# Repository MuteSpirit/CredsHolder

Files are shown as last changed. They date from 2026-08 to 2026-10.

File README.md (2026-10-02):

<!--
Copyright (C)  2026  Ivan Efimov aka MuteSpirit <mutespirit@yandex.ru>.

Permission is granted to copy, distribute and/or modify this document
under the terms of the GNU Free Documentation License, Version 1.3
or any later version published by the Free Software Foundation;
with no Invariant Sections, no Front-Cover Texts, and no Back-Cover Texts.
A copy of the license is included in the section entitled "GNU
Free Documentation License".
-->

# CredsHolder

Hardware credentials manager.

Secure replacement of stickers on monitor (and other similar stuff) with login and passwords.

CredsHolder makes it easier to use good complex and unique passwords for your accounts on different web sites and other applications. 

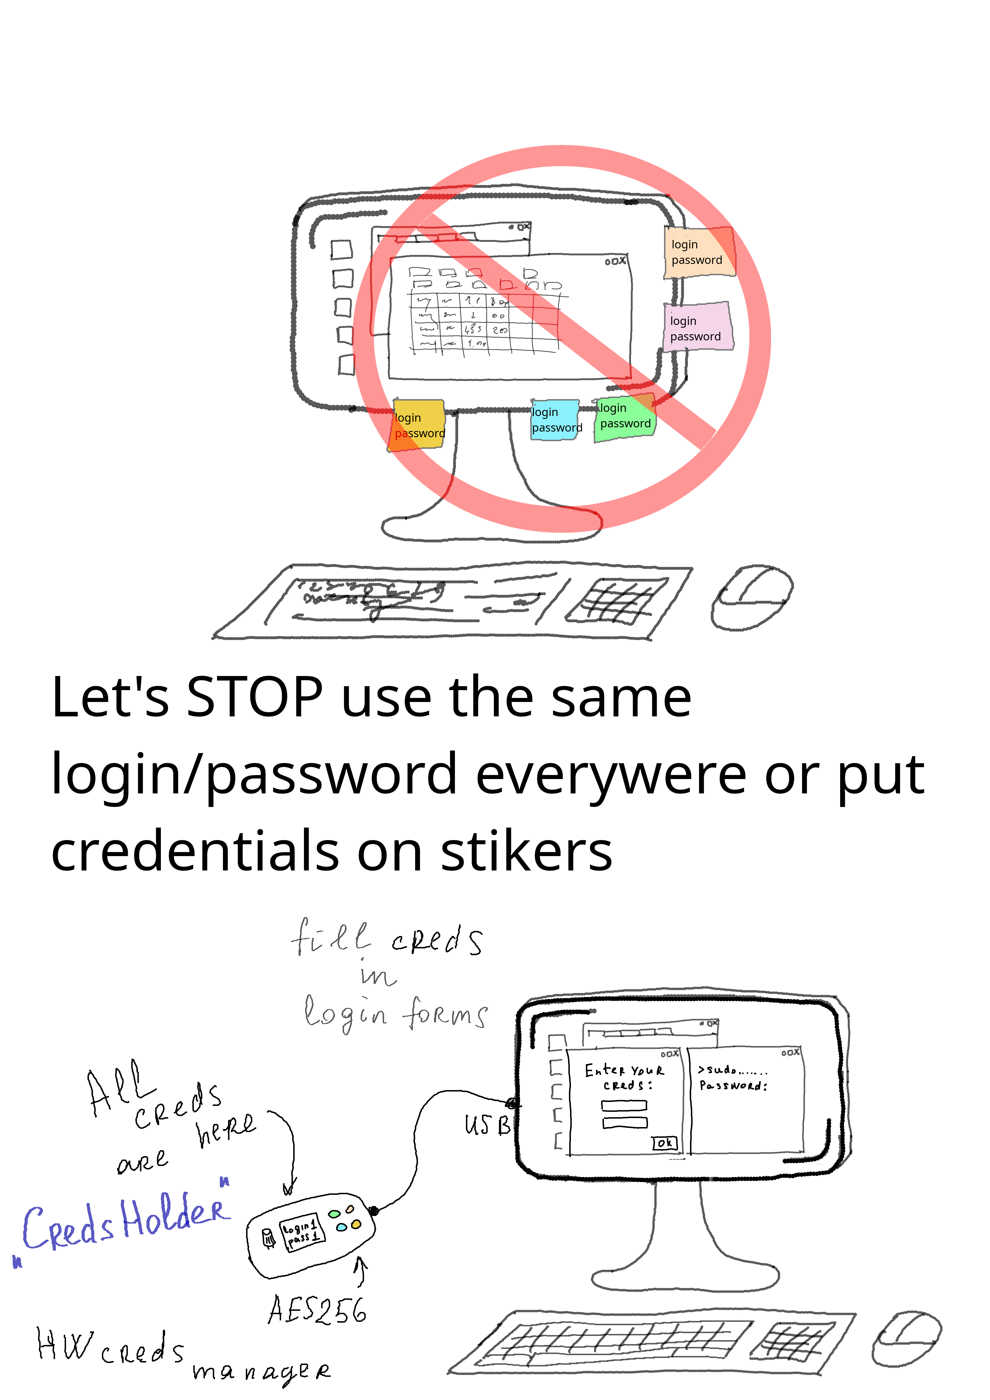
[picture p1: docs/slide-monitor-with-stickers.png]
Slide 1


## Code License

```
Hardware Credential Manager "CredsHolder"
Copyright (C) 2026 Ivan Efimov aka MuteSpirit <mutespirit@yandex.ru>

This program is free software: you can redistribute it and/or modify it under the terms of the GNU General Public License as published by the Free Software Foundation, either version 3 of the License, or (at your option) any later version.

This program is distributed in the hope that it will be useful, but WITHOUT ANY WARRANTY; without even the implied warranty of MERCHANTABILITY or FITNESS FOR A PARTICULAR PURPOSE. See the GNU General Public License for more details.

You should have received a copy of the GNU General Public License along with this program. If not, see <https://www.gnu.org/licenses/>.
```

## Documentation License

Copyright (C)  2026  Ivan Efimov aka MuteSpirit <mutespirit@yandex.ru>.

Permission is granted to copy, distribute and/or modify this document
under the terms of the GNU Free Documentation License, Version 1.3
or any later version published by the Free Software Foundation;
with no Invariant Sections, no Front-Cover Texts, and no Back-Cover Texts.
A copy of the license is included in the section entitled [GNU
Free Documentation License](COPYING.FDL-1.3.md).

# See Also

* [CredsHolder Project Requirements Doc](proposals/creds-holder.md)

# Project News

Current stage - MVP.

## 02 Oct 2026

* Demo variant:
  * no authentication
  * no storage on flash
  * 3 hard-coded accounts
  * accounts menu
  * account fields menu
  * typing login and password
  * navigation with device tilts (forward, backward, clockwise and counterclockwise)
  * vibration motor to feedback User about correct tilt angle

## 27 Aug 2026

* Project code license has been changed to GPLv3-or-later. See reasons in [relevant proposals](proposals/creds-holder-license.md).
* Project documentation license is [GNU Free Documentation License](COPYING.FDL-1.3.md) now.

## 21 Aug 2026

* Fritzing part for NRF52840 Pro Micro board finished. See [relevant README](./fritzing/README.md)
* Starting POC No 3 "VeraCrypt volume on microSD card (NRF52840 Pro Micro)"

## 19 Aug 2026

* Two POCs finished successfully:
  * POC No1 "UI with position sensor (Arduino Uno)" - see [README](poc/ui-mpu-6050-with-oled-on-arduino-uno/README.md)
  * POC No2 "UI with position sensor (NRF52840 Pro Micro)" - see [README](poc/ui-mpu-6050-with-oled-on-nrf52840/README.md)

## 17 Aug 2026

* [CredsHolder UI High Level Design](proposals/creds-holder-ui.md) with 3 possible variants of device UI

## 15 Aug 2026

* Finished [CredsHolder Storage High Level Design](proposals/creds-holder-storage.md)
  * Encrypted VeraCrypt volume on removable microSD card
  * PIN for CredsHolder unlock but custom complex password and non-default PIM for VeraCrypt volume encryption
  * FAT inside encrypted volume
  * Any suitable file format for application data, i.e. SQLite
  * See all details in design

## 13 Aug 2026

* Finished [CredsHolder Authentication High Level Design](proposals/creds-holder-auth.md)
  * PIN for CredsHolder authentication
  * No one button or encoder in Device
  * Enter PIN via Morse code
  * See all details in design

## 12 Aug 2026

* Finished [CredsHolder Project Requirements Doc](proposals/creds-holder.md)
* Low Level Design for Authentication is started

## 07 Aug 2026

* Close PasswordWand (clone of PasswordPump with modified code) project as deprecated
* Project has been renamed and started from scratch
  * Reason 1: license has been changed to MIT. I hope that will help for distribution.
  * Reason 2: device SW and HW redesign is needed. Original PasswordPump code base is very complex to be maintainable and extendable.
  * Reason 3: to be not a fork repo of PasswordPump will allow to configure Git LFS and store docs pictures originals in Git.
  * Reason 4: do at least OpenSource project design and development accordign all best practices and without rush.

## This project was originally fork of ...

... https://github.com/seawarrior181/PasswordPump

I'd like to thank Dan Murphy for PasswordPump. It's cool idea and device.
I'm appreciate how many features has been implemented in orignal sketch.

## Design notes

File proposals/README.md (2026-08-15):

# Proposals

| Doc | Comment | 
| --- | --- |
| [CredsHolder Project Requirements Doc](creds-holder.md) |  |
| [CredsHolder Authentication High Level Design](creds-holder-auth.md) | <br/>PIN will unlock device<br/>OLED will be hidden inside case or User will receive PIN suggestion using Morse code via vibration<br/>Concrete UI is not chosen |
| [CredsHolder Storage High Level Design](creds-holder-storage.md) | <br/>Encrypted VeraCrypt volume on removable microSD card together with VeraCrypt portable applications<br/>PIN for CredsHolder unlock but custom complex password and non-default PIM for VeraCrypt volume encryption<br/>VeraCrypt volume will have FAT FS and contain SQLite DBs with application data |
| [CredsHolder UI High Level Design](creds-holder-ui.md) | Doc is started |

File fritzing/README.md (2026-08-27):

<!--
Copyright (C)  2026  Ivan Efimov aka MuteSpirit <mutespirit@yandex.ru>.

Permission is granted to copy, distribute and/or modify this document
under the terms of the GNU Free Documentation License, Version 1.3
or any later version published by the Free Software Foundation;
with no Invariant Sections, no Front-Cover Texts, and no Back-Cover Texts.
A copy of the license is included in the section entitled "GNU
Free Documentation License".
-->

# Fritzing

## Self-done Parts

### Tenstar Robot NRF52840 Pro Micro

That microcontroller board Fritzing part was not founded in Internet and I had to do that myself.

Import next one into your Fritzing to be able use NRF52840 Pro Micro board in schemas: [NRF52840 Pro Micro](./parts/nrf52840_pro_micro/NRF52840 Pro Micro.fzpz)

Some notes:
* All needed parts Breadboard, Schematic, PCB, Connectors and Metadata has been added following [Fritzings Graphic Standards](https://fritzing.org/fritzings-graphic-standards) but ...
* .. I've tried to make board contacts as similar as possible to real board but I had no PDF/PostScript/SVG breadboard schema from manufacturer and there is absolutely no guarantee that exporting PCB will give expected results.
* So that fritzing part is good enough for making schemas in Fritzing and that's enough for nearest goals

#### Links

* https://www.beachyuk.com/blog/connecting-and-testing-promicro-nrf52840-clones
* https://github.com/ICantMakeThings/Nicenano-NRF52-Supermini-PlatformIO-Support#1
* https://doxygen.riot-os.org/group__boards__pro-micro-nrf52840.html
* https://tenstar.pro/nrf52840-pinout/
* https://chat.nologo.tech/d/80
* https://tinygo.org/docs/reference/microcontrollers/boards/nicenano/
* https://nrfconnectdocs.nordicsemi.com/ncs/3.2.4/zephyr/boards/others/promicro_nrf52840/doc/index.html

## Downloaded Parts

| | URL |
| :---: | :---: |
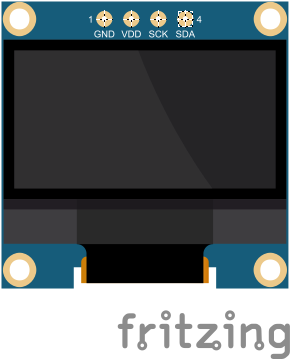
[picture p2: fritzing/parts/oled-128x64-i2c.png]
OLED 128x64 I2C
|  | [Link](https://github.com/AlexGyver/GyverKIT/blob/master/Fritzing%20parts/OLED%20128x64%20I2C.fzpz) |
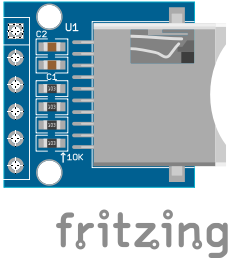
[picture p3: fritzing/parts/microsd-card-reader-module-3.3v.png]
MicroSD Card Reader 3.3V
|  | [Link](https://digitalconcepts.net.au/fritzing/content/support/parts/microSD%20Card%20Reader.fzpz) |
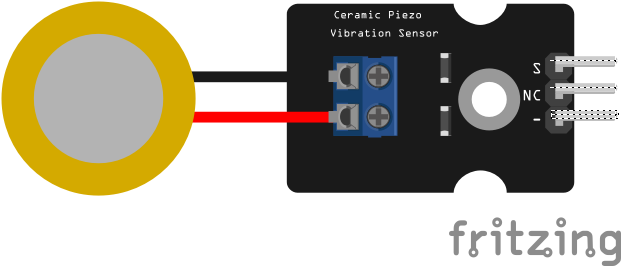
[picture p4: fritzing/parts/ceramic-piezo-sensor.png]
Ceramic Piezoelectric Sensor
|  | [Link](https://forum.fritzing.org/t/piezoelectric-ceramic-vibration-sensors/33600) |
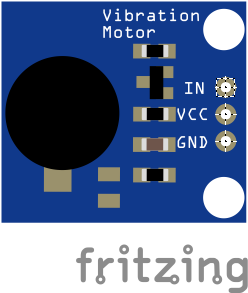
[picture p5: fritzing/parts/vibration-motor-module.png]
Vibration Motor Module 5V
|  | [Link](https://forum.fritzing.org/t/looking-for-a-vibration-module/26877) |

#### Links

* https://digitalconcepts.net.au/fritzing/index.php?op=parts

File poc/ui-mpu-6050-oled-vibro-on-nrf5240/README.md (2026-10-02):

# POC No 4 UI (OLED, MPU6050, vibration motor)

## Goal

Help user to sense needed tilt angle.

## Proposals

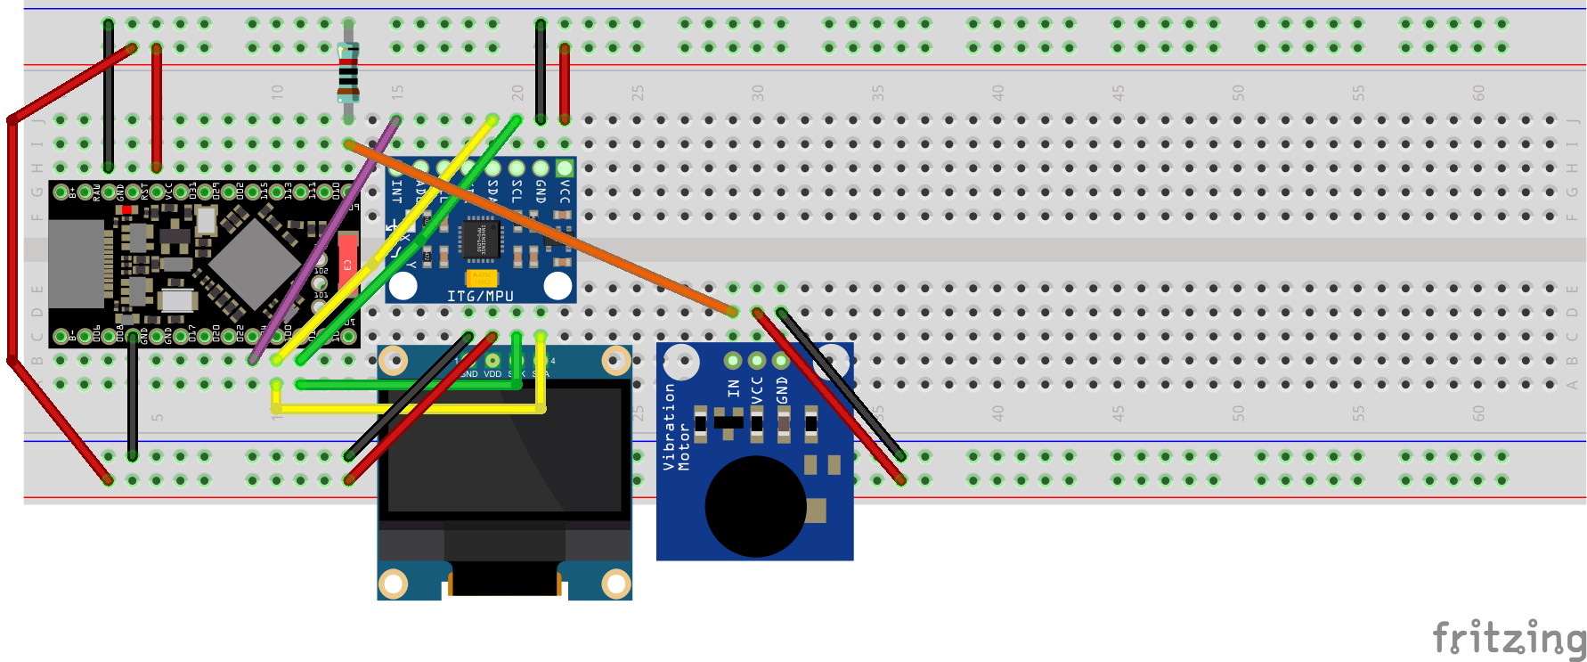
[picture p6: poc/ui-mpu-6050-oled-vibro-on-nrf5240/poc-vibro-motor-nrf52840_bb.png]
Breadboard Schema


Make very short vibration on tilting device up to threshold angle but before return device back to horizontal position.

## Results

Touching senses are cool. I'm feeling more navigation control.

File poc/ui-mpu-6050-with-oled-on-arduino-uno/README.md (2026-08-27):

<!--
Copyright (C)  2026  Ivan Efimov aka MuteSpirit <mutespirit@yandex.ru>.

Permission is granted to copy, distribute and/or modify this document
under the terms of the GNU Free Documentation License, Version 1.3
or any later version published by the Free Software Foundation;
with no Invariant Sections, no Front-Cover Texts, and no Back-Cover Texts.
A copy of the license is included in the section entitled "GNU
Free Documentation License".
-->

## Summary

POC proved that it's possible to detect device tilts (on left, on right, forward, backward) using MPU6050 and Arduino Uno as a controller:

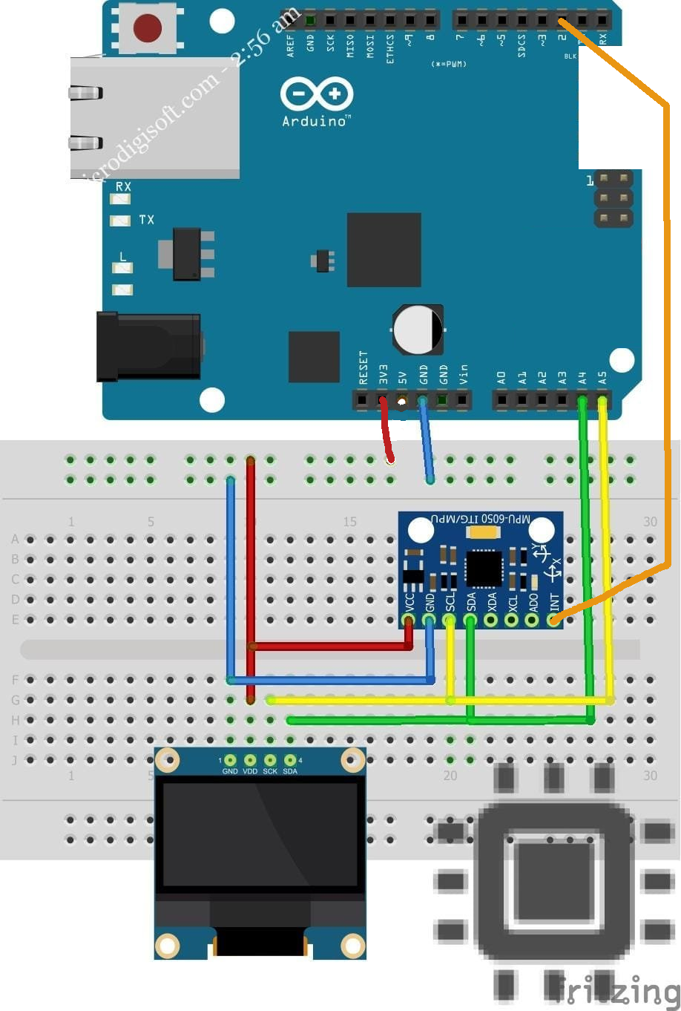
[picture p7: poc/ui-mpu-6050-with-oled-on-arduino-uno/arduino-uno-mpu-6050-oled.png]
UI POC schema


Sources are located in `./CredsHolderPOC/`

GY-521 with MPU6050 has been used because can work with 3.3V as NRF52840 and with 5V as Arduino.

MPU6050 DMP has been used because of measurement accuracy and ability to do that not on MCU and decrease requirements for it.

DMP also has motion detection capability so in future it'll be possible to improve power consumption and enable MCU sleep mode until device will be taken by User hands.

## Abbreviations and Terms

* POC - Proof Of Concept
* DMP - Digital Motion Processor

## Notes

Initial MPU-6050 calibration can be done via sketch: https://github.com/jrowberg/i2cdevlib/blob/master/Arduino/MPU6050/examples/IMU_Zero/IMU_Zero.ino

If use [MPU-6050 with DMP](https://github.com/jrowberg/i2cdevlib/blob/master/Arduino/MPU6050/examples/MPU6050_DMP6/MPU6050_DMP6.ino) then

* we a able to receive yaw, pitch and roll with good sensitive
* but in less then a minute sketch stuck due to FIFO overflow

Next steps to try:
* Try sketch MPU6050_6Axis_MotionApps612.cpp with newer DMP firmware version - v6.12
* Try sketch MPU6050_6Axis_MotionApps20.cpp with decrease fifo queue speed
* Handling FIFO overflow cleanly is also a good idea - for future

With DMP firmware v6.12 ( DLPF disabled?) and sample rate decreased to 100 Hz the stuck happen.

With DMP firmware v2.0  (accel +-2000, DLPF 42Hz) and sample rate decreased to 100 Hz there is no stuck.

With DMP firmware v2.0  (accel +-250, DLPF 42Hz) and sample rate decreased to 100 Hz there is no stuck but tilt detection is not possible because after tilt there is a period (~10 sec) of returning back to 0.

With DMP firmware v2.0  (accel +-250, DLPF 42Hz) and sample rate decreased to 200 Hz there is stuck

With DMP firmware v2.0  (accel +-500, DLPF 42Hz, fifo rate 100 Hz) there is stuck but later and value return back to ~0 during 2 sec

With DMP firmware v2.0  (accel +-500, DLPF 42Hz, fifo rate 125 Hz) there is stuck but later and value return back to ~0 during 2 sec

With DMP firmware v2.0  (accel +-1000, DLPF 42Hz, fifo rate 125 Hz) there is stuck but later and value return back to ~0 during 1 sec !!

**With DMP firmware v2.0  (accel sensitivity +-500 degress/sec, DLPF 42Hz, fifo rate 60 Hz) work is enough stable, measurements is about 1 time per second, tilt detection has been done.**

# Links

## Articles

* https://mjwhite8119.github.io/Robots/mpu6050
* https://alexgyver.ru/arduino-mpu6050/
* https://arduinokitproject.com/mpu6050-accel-gyro-arduino-tutorial/
* https://www.chrobotics.com/library

## Libraries

* https://github.com/jrowberg/i2cdevlib
* https://github.com/adafruit/Adafruit_MPU6050

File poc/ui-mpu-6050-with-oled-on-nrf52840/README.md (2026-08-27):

<!--
Copyright (C)  2026  Ivan Efimov aka MuteSpirit <mutespirit@yandex.ru>.

Permission is granted to copy, distribute and/or modify this document
under the terms of the GNU Free Documentation License, Version 1.3
or any later version published by the Free Software Foundation;
with no Invariant Sections, no Front-Cover Texts, and no Back-Cover Texts.
A copy of the license is included in the section entitled "GNU
Free Documentation License".
-->

# POC No2. Start use Tenstar Robot NRF52840 Pro Micro

## Goal

Run the same UI POC with MPU6050 + OLED 0.96 inch as POC No1 but using Tenstar Robot NRF52840 Pro Micro.

## Schema

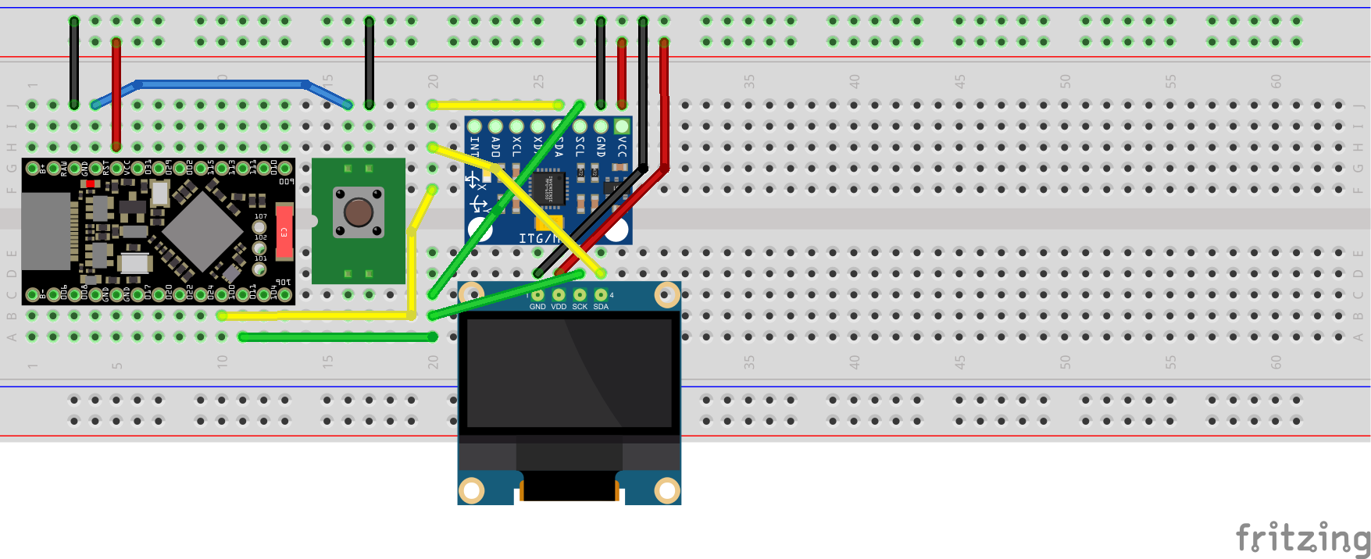
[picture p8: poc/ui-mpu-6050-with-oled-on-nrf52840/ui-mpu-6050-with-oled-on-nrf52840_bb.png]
Fritzing made schema


## Changes

POC No1 code did not work as-is and required next main changes:

* Changed numbers of PINs according NRF52840 board
* Up Serial speed up to 115200
* Remove increasing I2C bus speed 

```diff
diff --color -u ./ui-mpu-6050-with-oled-on-arduino-uno/CredsHolderPOC/CredsHolderPOC.ino ./ui-mpu-6050-with-oled-on-nrf52840/CredsHolderPOC/CredsHolderPOC.ino
--- ./ui-mpu-6050-with-oled-on-arduino-uno/CredsHolderPOC/CredsHolderPOC.ino	2026-08-19 16:23:57.760809528 +0500
+++ ./ui-mpu-6050-with-oled-on-nrf52840/CredsHolderPOC/CredsHolderPOC.ino	2026-08-21 21:06:20.894398901 +0500
@@ -41,8 +41,17 @@
 // more info, see: http://en.wikipedia.org/wiki/Gimbal_lock)
 #define OUTPUT_READABLE_YAWPITCHROLL
 
-#define INTERRUPT_PIN 2  // use pin 2 on Arduino Uno & most boards
-#define LED_PIN 13 // (Arduino is 13, Teensy is 11, Teensy++ is 6)
+// Arduino
+// #define INTERRUPT_PIN 2  // use pin 2 on Arduino Uno & most boards
+// #define LED_PIN 13 // (Arduino is 13, Teensy is 11, Teensy++ is 6)
+
+// NRF52840 Pro Micro
+// #define P0_24 (D5)
+#define INTERRUPT_PIN 5
+// In "variant.h" for Super Mini NRF52840:
+// #define PIN_LED              (22) // USR LED is P0.15
+#define LED_PIN 22
+
 bool blinkState = false;
 
 // MPU control/status vars
@@ -110,18 +119,12 @@
 
 void setup() {
   // join I2C bus (I2Cdev library doesn't do this automatically)
-#if I2CDEV_IMPLEMENTATION == I2CDEV_ARDUINO_WIRE
-  Wire.begin();
-  Wire.setClock(400000); // 400kHz I2C clock. Comment this line if having compilation difficulties
-#elif I2CDEV_IMPLEMENTATION == I2CDEV_BUILTIN_FASTWIRE
-  Fastwire::setup(400, true);
-#endif
-
   // initialize serial communication
   // (115200 chosen because it is required for Teapot Demo output, but it's
   // really up to you depending on your project)
-  Serial.begin(38400);
-  // while (!Serial); // wait for Leonardo enumeration, others continue immediately
+  // Serial.begin(38400); // Arduino
+  Serial.begin(115200); // nrf52840 pro micro
+  while (!Serial); // wait for Leonardo enumeration, others continue immediately
 
   // NOTE: 8MHz or slower host processors, like the Teensy @ 3.3V or Arduino
   // Pro Mini running at 3.3V, cannot handle this baud rate reliably due to
@@ -131,6 +134,14 @@
 
   // initialize device
   if (Serial) { Serial.println(F("Initializing I2C devices...")); }
+
+#if I2CDEV_IMPLEMENTATION == I2CDEV_ARDUINO_WIRE
+  Wire.begin();
+  // Wire.setClock(400000); // 400kHz I2C clock. Comment this line if having compilation difficulties
+#elif I2CDEV_IMPLEMENTATION == I2CDEV_BUILTIN_FASTWIRE
+  // Fastwire::setup(400, true);
+#endif
+
   mpu.initialize();
   pinMode(INTERRUPT_PIN, INPUT);
```

After that code start work as in POC No1.

One more thing has been tried - detect case tap/knock but without success, if tap during taking device in arms then we see acceleration increasing in 2 or all 3 axis sometimes.

## Conclusions

* We can continue use NRF52840 Pro Micro board
* MPU6050 as is not suitable To detect tap/knock. Let's try piezoelectric sensor for that in one of next POCs
* Plug board to separate USB port of your PC.
  * it'll be more stable then plug in USB hub port which communicate also you keyboards and trackball

## Notes

Original bootloader:

```
UF2 Bootloader 0.6.0 lib/nrfx (v2.0.0) lib/tinyusb (0.10.1-41-gdf0cda2d) lib/uf2 (remotes/origin/configupdate-9-gadbb8c7)
Model: nice!nano
Board-ID: nRF52840-nicenano
SoftDevice: S140 version 6.1.1
Date: Jun 19 2021
```

"Get board into" sketch from [article](https://www.beachyuk.com/blog/connecting-and-testing-promicro-nrf52840-clones) prints next:
```
23:15:32.168 -> --------------------------------------------------
23:15:32.168 -> ProMicro / SuperMini nRF52840 hardware information
23:15:32.168 -> --------------------------------------------------
23:15:32.168 -> Device ID: EB3536513509A804
23:15:32.168 -> Part: 00052840
23:15:32.168 -> Variant: AAD0
23:15:32.168 -> Package: 00002004 (QIxx - 7x7 73-pin aQFN)
23:15:32.168 -> RAM: 256 KB (262144 bytes)
23:15:32.168 -> Flash: 1024 KB (1.0 MB)
23:15:32.168 -> BLE MAC address: A9:0A:4B:AD:B5:37
23:15:32.168 -> Internal temperature: 24.00°C
23:15:32.168 -> Bootloader version: s140 7.3.0
```

I2C pins are located on non standard pins. Next is founded in `~/.arduino15/packages/nRFMicro-like-Boards/hardware/nrf52/1.0.2/variants/SuperMini_nRF52840/variant.h`:
```
/*
 * Wire Interfaces
 */
#define WIRE_INTERFACES_COUNT 2

#define PIN_WIRE_SDA         (6) // P1.00 - D6
#define PIN_WIRE_SCL         (7) // P0.11 - D7

static const uint8_t SDA = PIN_WIRE_SDA;
static const uint8_t SCL = PIN_WIRE_SCL;

#define PIN_WIRE1_SDA        (13) // P1.13 - D13
#define PIN_WIRE1_SCL        (14) // P1.15 - D14

```

# Links

* How burn using Arduino IDE: https://www.beachyuk.com/blog/connecting-and-testing-promicro-nrf52840-clones
* https://doxygen.riot-os.org/group__boards__pro-micro-nrf52840.html
* https://digitalconcepts.net.au/fritzing/index.php?op=partsu

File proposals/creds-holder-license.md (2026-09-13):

<!--
Copyright (C)  2026  Ivan Efimov aka MuteSpirit <mutespirit@yandex.ru>.

Permission is granted to copy, distribute and/or modify this document
under the terms of the GNU Free Documentation License, Version 1.3
or any later version published by the Free Software Foundation;
with no Invariant Sections, no Front-Cover Texts, and no Back-Cover Texts.
A copy of the license is included in the section entitled "GNU
Free Documentation License".
-->

# CredsHolder code license

## Introduction

This document is related to project license aspect. 

There are several contradiction requirements for that in [CredsHolder HLD Doc](creds-holder.md#Requirements) and it's needed to find optimal solution for that.

## Abbreviations and terms

| Term | Description |
| :---: | :---: |
| POC | Proof Of Concept. Prototype application to proof proposals idea(s) |
| TRNG | A True Random Number Generator |
| MBR | Master Boot Record |

## Requirements

| No | Re User Story | Requirement |
| --- | --- | --- |
| R-21 | S-8, S-12, S-14, S-17 | All source code and schematics MUST be OpenSource to allow any User assemble device and modify/build firmware. |
| R-30 | S-15 | CredsHolder code/FW MUST allow to extend encryption/hash algorithm and add something else. |
| R-34 | S-16 | CredsHolder License MUST allow commercial usage to allow any company make and sale CredsHolder based product. |
| R-38 | S-17 | All Vendors MUST public own changes into CredsHolder sources...<br/>or data on extractable storage MUST be reusable by another CredsHolder device. |

## Background

### Licenses

### Useful Libraries

According to several proposal documents and POCs made previously next libraries should be useful for project:

| Theme | Library | URL | Comment | License |
| --- | --- | --- | --- | --- |
| USB HID keyboard<b/>Bluetooth keyboard<b/>USB MassStorage | Adafruit_TinyUSB_Arduino | https://github.com/Adafruit/adafruit_tinyusb_arduino | Supports NRF52840 | MIT |
| I2C | ArduinoCore-avr/Wire | https://github.com/arduino/ArduinoCore-avr/tree/master/libraries/Wire | Needed for libraries works with OLED and MPU6050 | GPL-v2 or GPL-v2.1 or later |
| SSD1306 OLED display | SSD1306Ascii | https://github.com/greiman/ssd1306ascii | | MIT | 
| SSD1306 OLED display | Adafruit_SSD1306 | https://github.com/adafruit/Adafruit_SSD1306 | | BSD |
| SSD1306 OLED display | U8g2 | https://github.com/olikraus/u8g2 | | new-bsd license (two-clause bsd license) |
| NRF52840 internal NVM storage | arduino-NVM | https://github.com/d00616/arduino-NVM | | LGPL 2.1 only |
| Raw access microSD CardReader SPI | ArduinoCore-avr/SPI | https://github.com/arduino/ArduinoCore-avr/tree/master/libraries/SPI | | GPL-v2 or LGPL-v2.1 only |
| Raw access microSD CardReader SPI | Adafruit_SPIFlash | https://github.com/adafruit/Adafruit_SPIFlash | | MIT |
| FAT16, FAT32, MBR | SdFat | https://github.com/greiman/SdFat | | MIT |
| Position sensor (accelerator + gyroscope) MPU6050 | I2CDev | https://github.com/jrowberg/i2cdevlib | | MIT | 
| tilt detection | ? | ? | Not yet founded | ? |
| CLI over UART | SimpleCLI | https://github.com/spacehuhntech/SimpleCLI | | MIT |
| Cryptography acceleration<br/>TRNG | Adafruit_nRFCrypto | https://github.com/adafruit/Adafruit_nRFCrypto | Supports NRF52840 | MIT |
| VeraCrypt volume | VeraCrypt | https://github.com/veracrypt/VeraCrypt | C API | Apache License 2.0 and the TrueCrypt License version 3.0 |
| VeraCrypt volume | VeraCrypt-SDK | https://github.com/veracrypt/VeraCrypt | C++ API | Apache License 2.0 |
| LUKS volume header | libluksde | https://github.com/libyal/libluksde | GPL-v3.0, LGPL-v3.0 | 
| LUKS volume header | libcryptsetup | https://gitlab.com/cryptsetup/cryptsetup | GPL-v2.0-or-later | 
| SQLite3 | SQLite | https://sqlite.org/ | | Public Domain (copyleft if reuse original code) |
| Credentials Storage Alternative | Password Gorilla | https://github.com/zdia/gorilla | | GPLv2 or later |
| Credentials Storage Alternative | KeePassXC | https://github.com/keepassxreboot/keepassxc | | GPLv2 or GPLv3 |
| Credentials Storage Alternative | gopass | https://github.com/gopasspw/gopass | | MIT |
| Credentials Storage Alternative | PasswordSafe | https://github.com/pwsafe/pwsafe | [compatible with GPL](https://www.gnu.org/licenses/license-list.html#ArtisticLicense2) | Artistic License 2.0 |
| UI interface | Adafruit GFX | https://github.com/adafruit/adafruit-gfx-library | | BSD | 
| secure boot, non immutable bootloader | Nordic nRF Connect SDK | https://github.com/nrfconnect/sdk-nrf/ | Can be used with mentioning copyright notice.<br/>bootloader is separate code and binary and has no license relation to application code license | LicenseRef-Nordic-5-Clause |
| NRF52840 board support in Arduino IDE | | https://github.com/pdcook/nRFMicro-Arduino-Core | | GPL-v2.1 or later |
| Unit Tests on target board | AUnit | https://github.com/bxparks/AUnit | | MIT |
| Unit Tests on host | EpoxyDuino | https://github.com/bxparks/EpoxyDuino | Some mock libraries for Arduino are supported but no mentions about nRF52. Need to be adapted. | MIT |
| (alternative to position sensor UI) Rotary Encoder | RotaryEncoder | https://github.com/mathertel/RotaryEncoder | will be needed if UI based on MPU6050 failed | BSD |
| Tap/knock detection via Piezo Sensor | | https://docs.arduino.cc/built-in-examples/sensors/Knock/ | Separate lib is not needed | Public Domain |
| Morse code via vibrations | | | Separate lib is not needed | |
| Intro Tutorial via Snake Game | https://github.com/aydakikio/arduino_snake | | MIT |

### Code Licenses

Next licenses is compatible with project using MIT/BSD license:
* MIT
* BSD
* Apache License 2.0

LGPL is also usable if linked dynamically with our application. But not for Arduino like embedded systems - all libraries are linked statically if e.g. you develop code in Arduino IDE.

License as GPL v2/v3 requires public sources of application using library under GPL license. So GPL v2.x/v3.x are not usable in project with MIT license.

See [GPL licenses compatibility](https://www.gnu.org/licenses/gpl-faq.html#AllCompatibility).

See [GNU article about licenses](https://www.gnu.org/licenses/license-list.html).

## Contradictions

* Arduino/nRF52 based embedded projects cannot use dynamically linked libraries.
* Not all GPL licenses are compatible, e.g. (L)GPLv3-or-later cannot use GPLv2-only and vice versa - see [compatibility table](https://www.gnu.org/licenses/gpl-faq.html#AllCompatibility)
* Some core libraries like [NRF52840 board support in Arduino IDE](https://github.com/pdcook/nRFMicro-Arduino-Core) use GPL license and there is no alternative for that.
* Project with MIT license cannot use libraries under GPL licenses.

## Proposals

Change license to GPL v3 or later versions.

Reasons:
* Compatibility with any license used in libraries needed in project
* Force proprietary project based on CredsHolder (I hope that they will appear eventually :-) ) share their code changes with OpenSource community.

Advantages:
* Ability to use libraries with any Open Source licenses. That will decrease project development effort.
* Requirement R-30 and R-34 will be able to met too if company which make a CredsHolder based product will open own source changes.
  * According to [GPL FAQ](https://www.gnu.org/licenses/gpl-faq.html#DoesTheGPLAllowMoney) the code can be sold. [Trezor Wallet](https://trezor.io/) and [Mooltipath](https://www.themooltipass.com/) are examples of such commercial schema.
* Security and encryption is very complex themes and keep them as Open Source allows to review the code and start to trust it.
* Increasing chances to meet requirement R-38: if commercial project code changes will be published then it'll be theoretically possible to write recover/import code for encrypted storage of proprietary device(s).

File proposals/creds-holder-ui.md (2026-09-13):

<!--
Copyright (C)  2026  Ivan Efimov aka MuteSpirit <mutespirit@yandex.ru>.

Permission is granted to copy, distribute and/or modify this document
under the terms of the GNU Free Documentation License, Version 1.3
or any later version published by the Free Software Foundation;
with no Invariant Sections, no Front-Cover Texts, and no Back-Cover Texts.
A copy of the license is included in the section entitled "GNU
Free Documentation License".
-->

# CredsHolder UI

## Introduction

This document is related to usage input and output methods in CredsHolder.

We'll try to find answers to next questions:
* how User will manage device?
* how CredsHolder will show information to User?

## Abbreviations and Terms

* IFR - Ideal Finish Result
* Device - CredsHolder, current project main theme
* POC - Proof Of Concept

## Requirements

| No | User Story |
| --- | --- |
| S-4 | As an User I'd like that CredsHolder will fill login form/prompt itself. |
| S-5 | As an User I'd like to store about 1000 accounts on CredsHolder. |
| S-7 | As a Developer I'd like to develop new features for CredsHolder but Users will not have to buy to model to start use them. |
| S-11 | As an User I'd like be able use CredsHolder by one human arm, left or right. |
| S-16 | As a Developer I'd like that CredsHolder become widely usable all over the world. |

In scope of UI design we must list more concrete User action scenarios happen during work with CredsHolder:
* Configure PIN at first CredsHolder turn on
* Type PIN for unlock CredsHolder
* Type "Recovery Code" (password and PIM)
* Change settings (boolean, numeric, string list)
* Navigate between credential accounts
* Initiate login form filling by CredsHolder
* Lock CredsHolder

If go deeper then next input actions should be supported:
* Move Up
* Move Down
* Move Left
* Move Right
* Backspace
* Enter, Confirm, Accept
* Switch group of entering symbols
* Lock device

## Background

The question about UI was addressed in "Authentication" design.

We listed possible variants, not only used in another similar projects:

| Input method | |
| :---: | :---: |
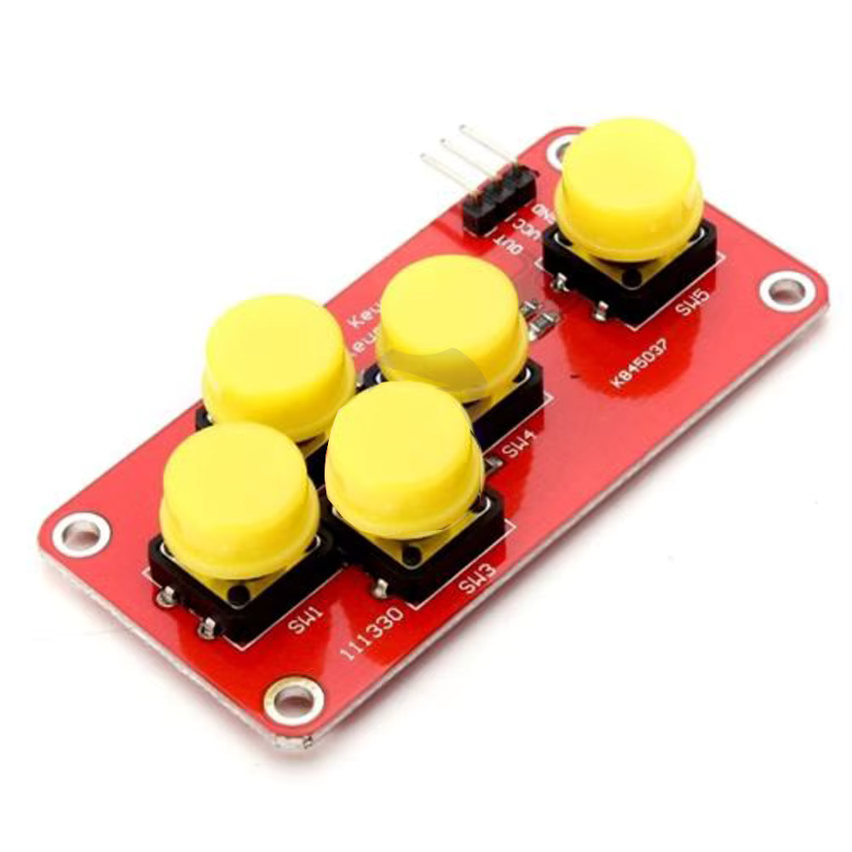
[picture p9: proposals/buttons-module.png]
Buttons
| Rotary encoder/wheel |  |
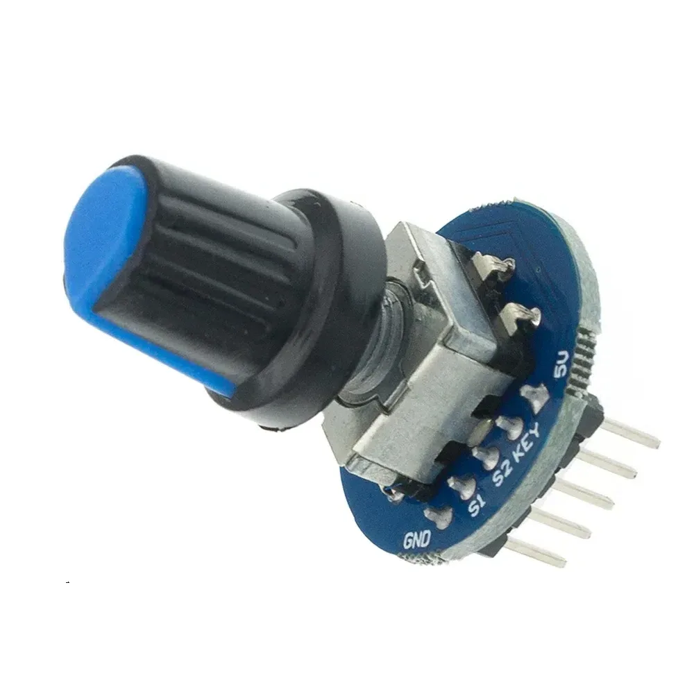
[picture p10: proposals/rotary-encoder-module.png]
Rotary Encoder
| Group of buttons |  |
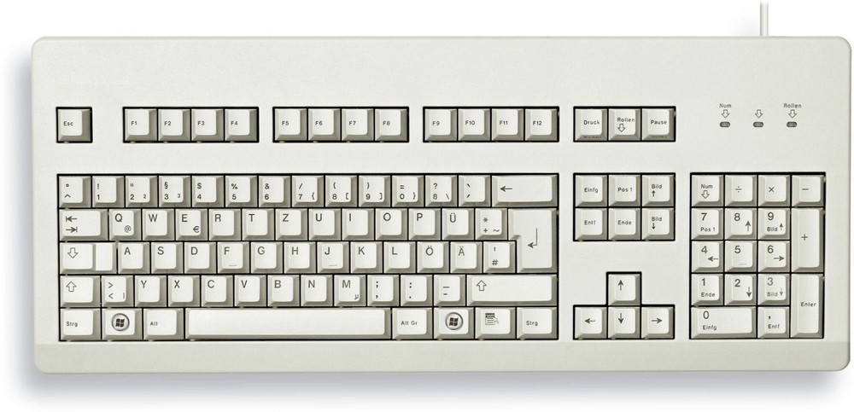
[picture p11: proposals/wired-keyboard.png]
104-keys Keyboard
| Full keyboard |  |
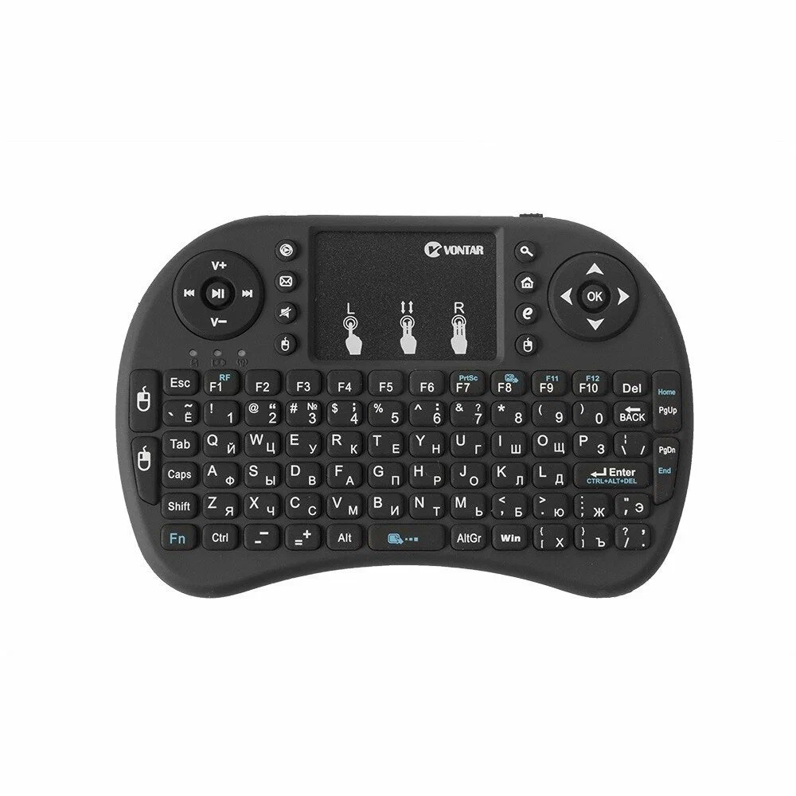
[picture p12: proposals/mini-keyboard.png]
Mini Wireless Keyboard
| Mini keyboard |  |
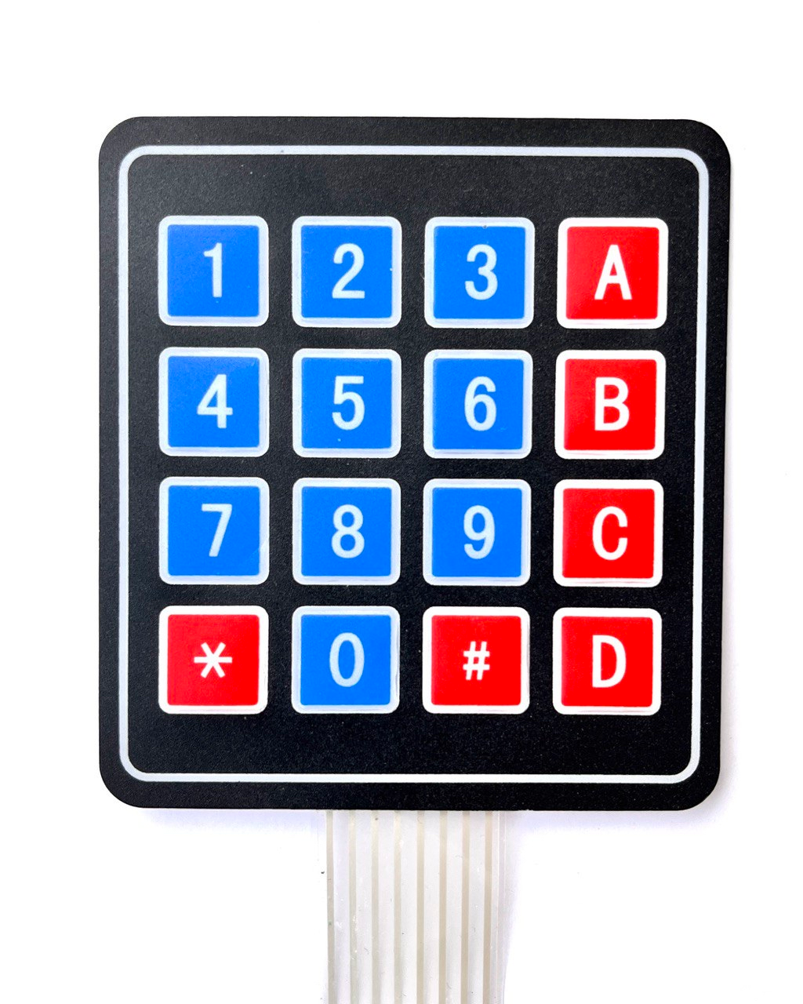
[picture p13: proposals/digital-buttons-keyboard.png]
4x4 matrix keyboard
| PIN keyboard |  |
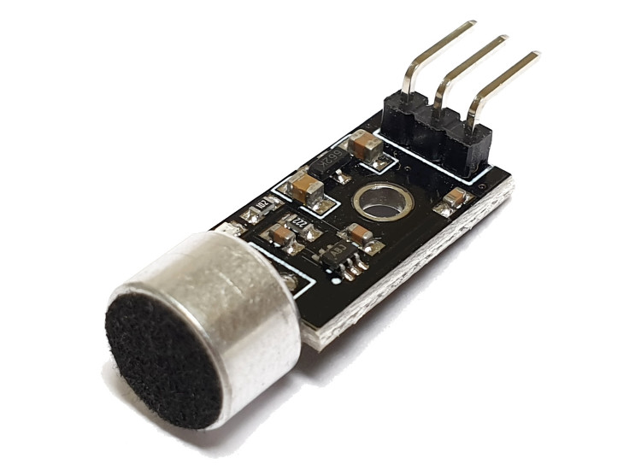
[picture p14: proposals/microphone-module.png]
Microphone module
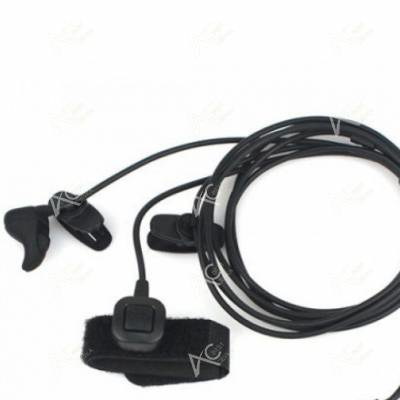
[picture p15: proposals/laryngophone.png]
Laryngophone
| Microphone, Voice | <br/>:heavy_plus_sign:<br/> |
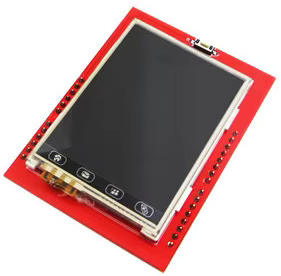
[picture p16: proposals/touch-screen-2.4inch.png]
2.4 inch touch LCD
| Touch LCD |  |
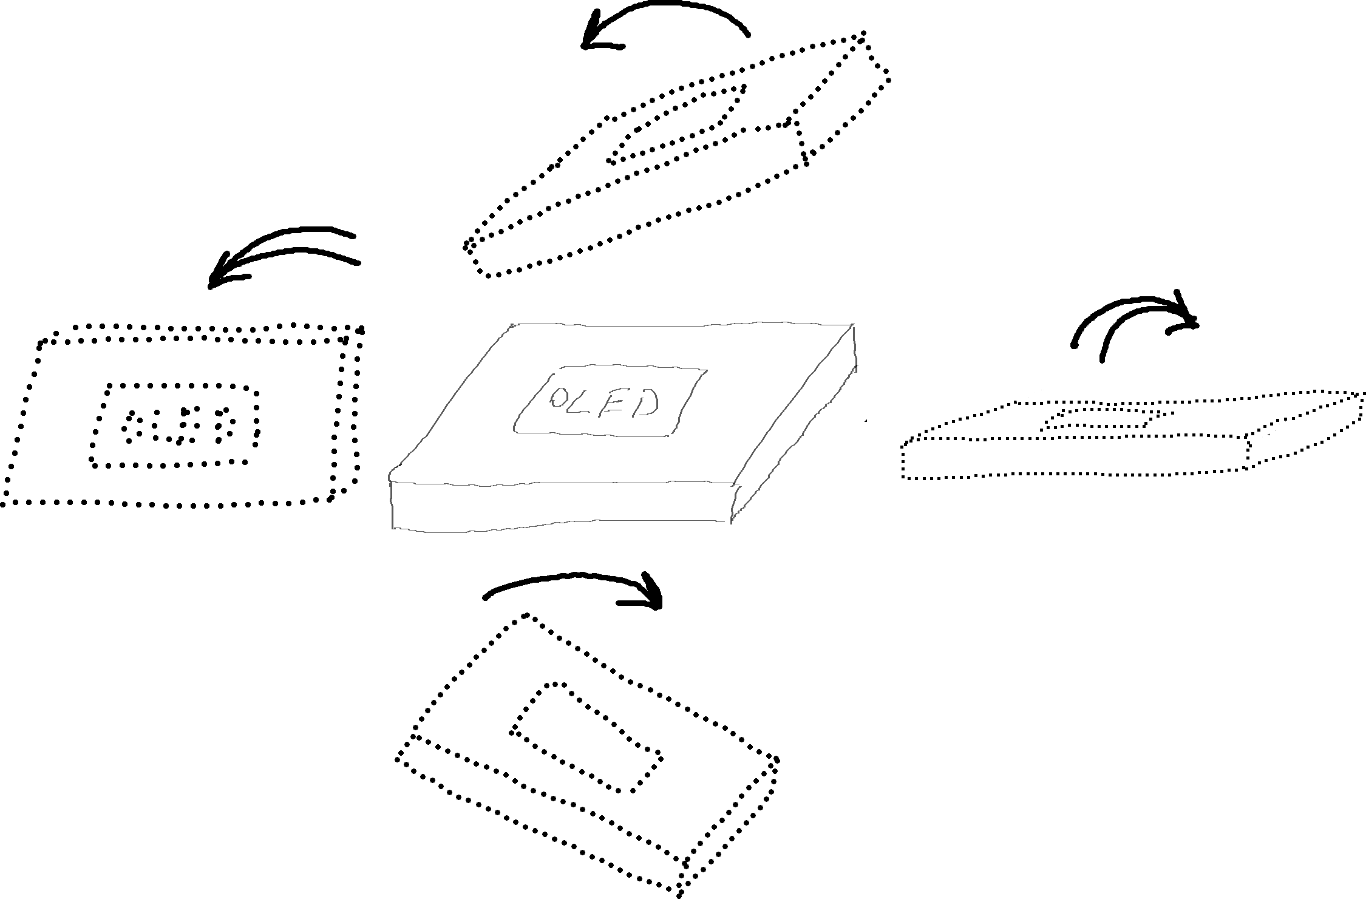
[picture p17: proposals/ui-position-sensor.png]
Movements
| Position sensor |  |
| Microphone, knock detection | |
| Microphone, Morse code detection | |
| Piezoelectric sensor, knock detection | |
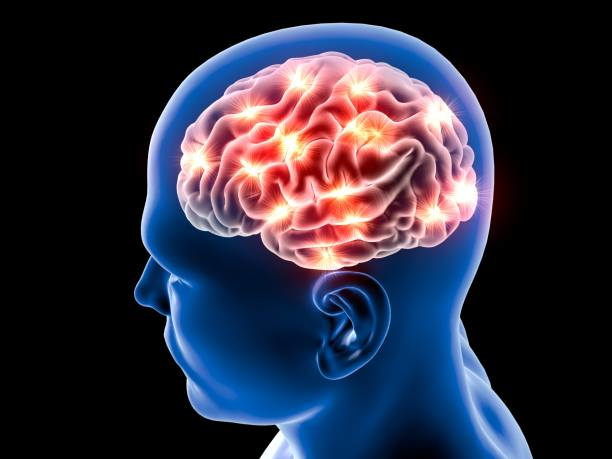
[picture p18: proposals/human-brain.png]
Human Brain
| Human mind (Sci-Fi) |  |

| Output method | |
| :---: | :---: |
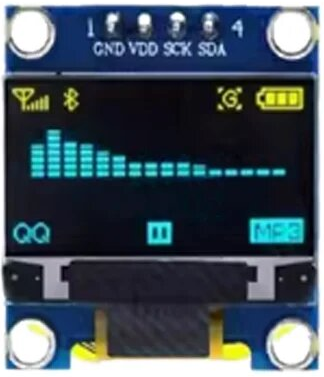
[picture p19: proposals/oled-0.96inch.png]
0.96 inch OLED
| OLED 0.96 inch |  |
| Touch LCD | 2.4 inch touch LCD |
| Speaker, Sound  | | 
| Audio card, Sound, Headset | |
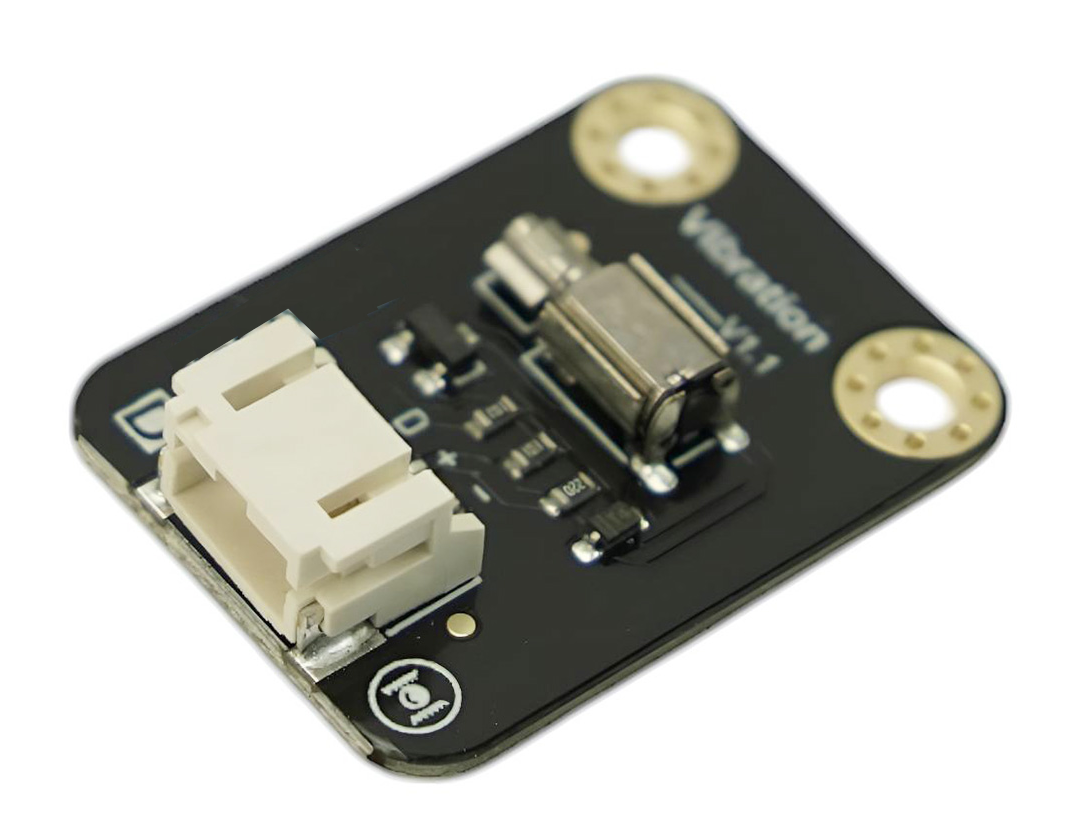
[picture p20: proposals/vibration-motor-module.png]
Vibration Motor Module
| Vibration motor, Morse code |  |
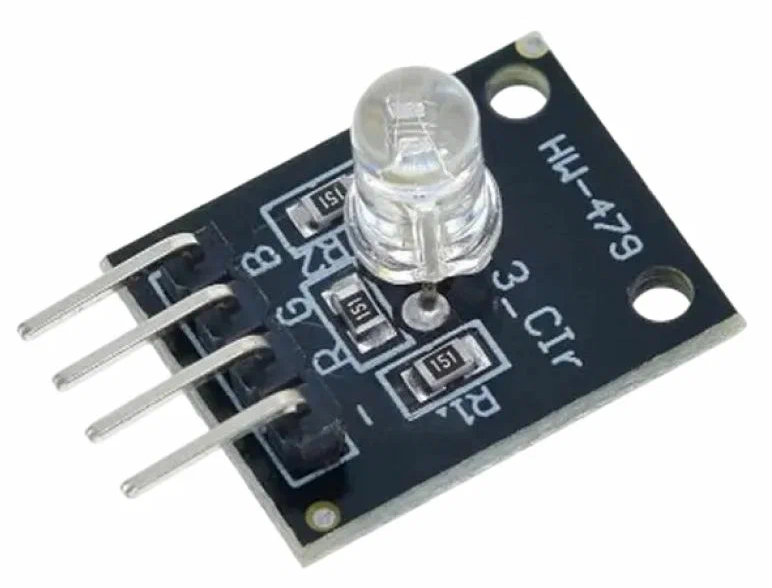
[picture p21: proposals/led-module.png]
LED module
| Multi color LED |  |
| Human mind (Sci-Fi) | Human Brain |

Note: "Human mind" has been added just an example that in future device maybe significantly improved after appearing new human-machine communication technologies.

## Proposals

### Entities

* Case
* Controller 
* Display
* Device Inputs (buttons, encoder, ...)
* Device sensors (accelerometer, gyroscope, microphone, reed switch, etc.)
* Device Outputs (display, speaker, vibration, LED)
* Human senses
* Human body
* Surrounding environment (atmosphere, sounds, light, pressure, humidity, etc.)
* Developer

It's need to pay into account that it's possible to use combinations of input hardware listed in previous section.

### Contradictions

What contradictions appear if one of next really available input methods will be added:

| Input method | |
| --- | --- |
| Rotary encoder/wheel | User will be able to perform two actions<br/>because push encoder is not stable and not available for wheel<br/>So it's only auxiliary input for another variant. |
| Group of buttons | User will able to perform all needed action if use single push, long push, double push, two buttons simultaneous push<br/>But that increase amount of components in schema<br>/And buttons usage is not intuitive because it's not a keyboard<br/>I guess the most known mobile device with small amount of buttons is joystick or portable play station<br/>If make buttons similar to joystick then "quick start" will be possible.<br/>But at the same time it'll be not trivial to make device compact and sable by one arm simultaneously |
| Full keyboard | <br/>User will be able to perform any actions<br/>But use cases is limited to home/office because nobody will take keyboard to walk |
| Mini keyboard | <br/>User will be able to perform any actions<br/>But use cases is limited to home/office because almost nobody will buy mini keyboard and bring it together with CredsHolder |
| PIN keyboard | If add PIN keyboard then it'll easier to enter PIN for authentication<br/>But it can be recorded by outside video camera and PIN will be vulnerable<br/>And in another scenarios it's not needed such amount of buttons and it's not the most optimal schema |
| Microphone, voice | User will be able to perform any actions<br/>But communication maybe slower<br/>And voice recognition may not work for you (just remember Barry Kripke from "Big Bang Theory")<br/>And requirements for Controller will be higher because of AI voice recognition usage |
| Touch LCD | <br/>User will be able to perform any actions<br/>And you will have a freedom to write any GUI interface, buttons and etc.<br/>And schema will be enough compact</br>And anti spy glass may be assumed as enough to hide screen from Intruder spying<br/>But there will be higher requirements for minimal RAM and CPU, Arduino is not good enough and similar MCU, for NRF52840 you will always have a risk to reach RAM limit<br/>And  |
| Position sensor (accelerometer + gyroscope) | <br/>User will able to perform actions:<br/>1. Tilt Backward (= Move Down)<br/>2. Tilt Forward (= Move Up)<br/>3. Tilt Left (= Move Left)<br/>4. Tilt Right (= Move Right)<br/>5. Turn upside down (= Lock)<br/>6. Knock (= Enter/Accept)<br/>7. Shake horizontally (= "Switch")<br/>8. Shake vertically (= ???)<br/>And device will be more compact<br/>And it'll be usable by one hand<br/>:+1: And it'll be cheap<br/>:+1: And requirements for Controller will be lower<br/>But device will have to use cable (or wireless interface) to connect to User equipment because if plugged to USB port directly then movements of device are not available<br/>And development complexity is unknown<br/>And usability in non ideal conditions is unknown<br/>And calibration is needed from time to time |
| Microphone, knock detection | User will able to perform one action ("Enter/Accept" or "Backspace")<br/>And can help to stably detect knocking<br/>But not all required action will be available so it's also only auxiliary input for another variant |
| Microphone, Morse code detection | <br/>User will be able to enter numeric and alpha symbols<br/>But not perform another required actions<br/>And only minimal percent of people knows Morse code |
| Position sensor or/and Piezoelectric sensor, knock detection | <br/>Only one action will be available for User<br/>And more stable knock detection will be done<br/>But more actions MUST be available |

What contradictions appear if one of next really available output methods will be added:

| Output method | |
| --- | --- |
| OLED 0.96 inch | <br/>Small and compact but enough for such project as proved by PasswordPump |
| Touch LCD | <br/>User will receive all needed information<br/>But you have risks and limitations with RAM size |
| Speaker, Sound  | <br/>User may receive all information<br/>And device usage will be available for people with bad vision<br/>But communication will be significantly slow then via display |
| Audio card, Sound, Headset | the same contradiction as for previous item |
| Vibration motor, Morse code | User will be able to accept suggested digits during authentication<br/>But it's enough paranoid process which will be not accepted by everybody |
| Multi color LED, show CredsHolder state (locked/unlocked, in authentication, etc.) | User will be able to receive auxiliary signals<br/>But as a result LED maybe used only together with another outputs |
| Multi color LED, suggested PIN digits during authentication using Morse code | If User will recognize PIN digits for input watching LED blinking<br/>then it may be watched by Intruder too |

Let's think what combinations of inputs and outputs will give the best results with minimum hardware schema influence.

Maybe besides Position sensor together with vibration motor because the first one may detect vibration of second one as a knocking. (I think it maybe solved by using them in different time slots).

According to information above there are three more or less optimal UI:
1. Output is 0.96inch OLED and vibration motor. Input is device movements detected by position sensor (accelerometer + gyroscope)
2. Touch LCD is as both input and output
3. Output is 0.96inch OLED and encoder + group of buttons as input

POC is needed to prove Option 1. Let's try to find out how stably detect:
* 1. Tilt Backward (= Move Down)
* 2. Tilt Forward (= Move Up)
* 3. Tilt Left (= Move Left)
* 4. Tilt Right (= Move Right)
* 5. Turn upside down (= Lock)
* 6. Knock (= Enter/Accept)
* 7. Shake horizontally (= "Switch")
* 8. Shake vertically
* 9. Knocking device case

## UI Option 1 Navigation

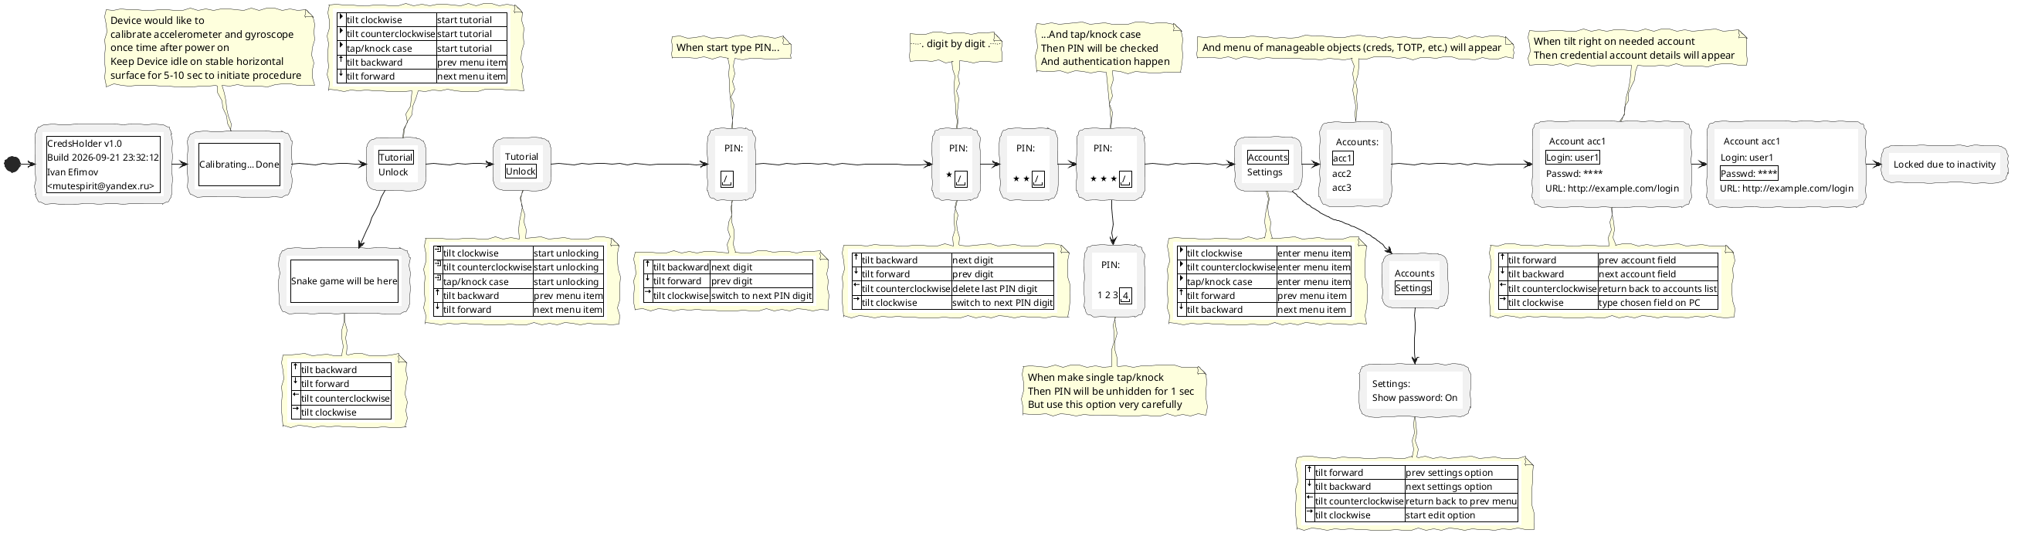
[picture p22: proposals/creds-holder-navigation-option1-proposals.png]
UI Option 1 Navigation


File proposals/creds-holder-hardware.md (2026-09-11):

<!--
Copyright (C)  2026  Ivan Efimov aka MuteSpirit <mutespirit@yandex.ru>.

Permission is granted to copy, distribute and/or modify this document
under the terms of the GNU Free Documentation License, Version 1.3
or any later version published by the Free Software Foundation;
with no Invariant Sections, no Front-Cover Texts, and no Back-Cover Texts.
A copy of the license is included in the section entitled "GNU
Free Documentation License".
-->

# Hardware

No SMD components. The device MUST be able to make at home with favorite soldering station using components from Ali Express

Add 3-colored LED to have ability show current mode - locked, authentication, unlocked

## Controller

Arduino Pro Micro

1. NRF52840 - with TrustZone - https://ali.click/aj86j1w: 
  * 64MHz, 256kB RAM, 1MB flash
  * ARM TrustZone CryptoCell-310 - https://www.micro-semiconductor.com/datasheet/c0-NRF52840-QIAA-R.pdf
2. STB32U5 - with TrustZone - https://ali.click/5i86j1h:
  * 160MHz, 786kB RAM, 2MB flash
  * Cortex-M33 TrustZone - https://www.st.com/resource/en/application_note/an5421-getting-started-with-stm32-mcus-and-armtrustzone-development-stmicroelectronics.pdf
3. STM32WB35
  * In Ledger Crypto Wallet
  * Secure Element: ST33K1M5C
4. Seeed Studio XIAO nRF52840 Sense

## Peripherals

Gyroscope and accelerometer:
- GY-521 (MPU-6050) - easy to start, many tutorials and libraries
- GY-LSM6DS33 - 3 axis, interrupts are supported, libraries from Adafruit and Pololu
* BMI160 - ADC (analog digit converter) inside, enough accuracy and low power consumption

### Random generator

TBD

For Arduino - WDT signals, library Entropy 

### Keyboard emulation

https://github.com/mooltipass/minible#manual-credential-typing
```
Manual Credential Typing
Mooltipass devices can simulate key presses in order to type logins & passwords onto the computer they're connected to. As the "byte sent on the wire" to "actual character typed on the computer" conversion is handled by the computer itself, that meant the Mooltipass devices need to handle multiple keyboard layouts.
For the Mooltipass Mini BLE, we are parsing the CLDR to make sure we can type text on any device.
```

### Link with PC

| Option | Advantages | Disadvantages |
| USB cable | 1. No way to sniff signal remotely because signal is digital and shielded cables<br>2. USB connector adapters to type-c, microUSB, etc. are exist<br>3. USB adapters increase device price<br>4. USB adapters requires place in case to put inside to avoid loss or it's needed some one combined USB-A & USB-C connector<br>5. Explicitly known what PC is plugged | 1. Maybe less usable then wireless link<br>2. Limited cable length |
| Bluetooth | 1. Signal encryption is possible (AES-MAC is used since BLE v4.0)<br>2. There are less cables and then increased device physical usability | 1. Not all PCs support Bluetooth.<br>2. Battery is needed in device, which increasing device price.<br>3. (corner case) Try to type password on locked device without preliminary pairing by Bluetooth. |
| Radio channel | | 1. Separate radio dongle is needed<br>2. Separate radio transmitter is needed in advance to integrated Bluetooth in NRF52840 |

According to table above the USB cable usage looks more optimal at least for 1st version.

# Links

* ETL (C++ Embedded STL) https://www.etlcpp.com/
* https://github.com/thirdpin/pastilda/
* https://github.com/trezor/trezor-firmware/tree/main
* https://github.com/mooltipass
* https://github.com/LedgerHQ/
* [nrf52 immutable bootloader](https://nrfconnectdocs.nordicsemi.com/ncs/2.0.1/nrf/samples/bootloader/README.html)
* [nrf52 secure bootloader chain](https://nrfconnectdocs.nordicsemi.com/ncs/2.0.1/nrf/ug_bootloader.html#immutable-bootloader)
  * `The immutable bootloader is flash-locked and cannot be modified or deleted without erasing the entire device.`

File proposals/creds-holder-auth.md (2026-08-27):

<!--
Copyright (C)  2026  Ivan Efimov aka MuteSpirit <mutespirit@yandex.ru>.

Permission is granted to copy, distribute and/or modify this document
under the terms of the GNU Free Documentation License, Version 1.3
or any later version published by the Free Software Foundation;
with no Invariant Sections, no Front-Cover Texts, and no Back-Cover Texts.
A copy of the license is included in the section entitled "GNU
Free Documentation License".
-->

# CredsHolder Authentication

## Introduction

This document is a Low Level Design for CredsHolder feature "Authentication". It's about unlocking CredsHolder, it's NOT about credentials stored inside.

We'll try to find the optimal way to protect CredsHolder from non-authorized access.

It's important part of CredsHolder because main differences of other Hardware Credential Manager projects in authentication method.

We figure out how User will we authenticated, what input/output devices (buttons, displays, etc.) will be needed for that.

Assume that R-10 "Navigation" is out of this design scope.

## Abbreviations and Terms

* HW - hardware
* Hardware Credential Manager - separate device which store credentials
* HLD - High Level Design (see [CONTRIBUTING.md](/CONTRIBUTING.md) for details)
* LLD - Low Level Design (see [CONTRIBUTING.md](/CONTRIBUTING.md) for details)
* OTP - One Time Password
* KEK - Key Encryption Key - key encrypted MEK
* MEK - Media Encryption Key - key encrypted application data (credential accounts)
* SOC - System On Chip
* Controller - Device central control module - Arduino, NRF52840, STM32, etc.
* NFC - Near Field Communication - communication technology for distances less 10 cm
* PIN - Personal Identification Number

## HLD Requirements

RE: [CredsHolder Project Requirements Doc](./creds-holder.md)

| No | User Story |
| --- | --- |
| S-18 | As a User I'd like to change authentication key (master password, etc.) if it was vulnerable. |

| No | Re User Story | Requirement |
| --- | --- | --- |
| R-24 | S-10 | CredsHolder MUST authenticate User before grand access to application data. |
| R-25 | S-10 | If User assumes that CredsHolder cannot be stolen then it should be able to turn authentication off. So ownership of CredsHolder will mean passed authentication. |
| R-20 | S-7 | Option 1. CredsHolder SHOULD support easy installing additional components with shields. <br/> :-1: increased complexity<br/>:-1: bigger case size <br/>Option 2. Needed components SHOULD be part of MVP model.<br/>:-1: increased prise<br/>:+1: incremental development of usable CredsHolder version<br/>:+1: chance to add additional functions to device, e.g. alarm clock)<br/>Option 3. CredsHolder is always DYI device. <br/>:-1: contradiction with S-16 <br/>So if we decided to develop turning on a blue/green LED after pass authentication in release after MVP, then MVP hardware schema MUST contain LED which will not work in MVP version. |
| S-19 (optional) | As a Corporate Employee I'd like to be able remotely unlock CredsHolder, e.g. one employee say password by phone to another employee. |
| R-41 (optional) | S-19 (optional) | CredsHolder MUST allow password authentication. Maybe like alternative method. |

## Proposals

* User unblocks CredsHolder with PIN
* CredsHolder has no buttons or rotary encoder. All manipulations via movements of Device: forward lean, backward lean, shake horizontally, etc.
* PIN will be entered with randomization: 
  * sequence of entering PIN position is random
  * sequence of scrolling digits to choose for position is random too.
* CredsHolder does not show PIN on display but ask what position and what digit to enter using Morse code via vibrations
* Auto-logout:
  * User may log out explicitly.
  * Auto-logout after some period without User activity. It's a backup for case when User forgot to lock CredsHolder.
  * Logout if User turn CredsHolder upside down
  * Logout if User dropped the device

## Proposals designing chain

At first, let's list variants how User can prove that he is CredsHolder owner:

| Authentication Method | User use... | CredsHolder UI | Comment |
| :---: | :---: | :---: | :---: |
| No Password, No Authentication | CredsHolder Ownership | No addition for Auth | Only for restricted area usage or in special cases |
| Password | wired/wireless full format keyboard<br/>104-keys Keyboard | USB-B port to connect keyboard cable or radio adapter<br/>Display to show password | :+1: easy to type any text<br/> :+1: arrow buttons are present<br/>:-1: it's not mobile device, keyboard is needed |
| Password | wired/wireless mini keyboard<br/>Mini Wireless Keyboard | USB-B port to connect keyboard cable or radio adapter<br/>Display to show password | :+1: possible to type any text<br/>:+1: arrow buttons are present<br/>:-1: difficult to work by one hand |
| Password | - | Rotary-Encoder(or Wheel) + Buttons<br/>Buttons<br/>:heavy_plus_sign:<br/>Rotary Encoder | :+1: possible to type a word<br/>:+1: no additional equipment<br/>:+1: theoretically it's possible to do that by one hand<br/>:-1: non minimalistic device size |
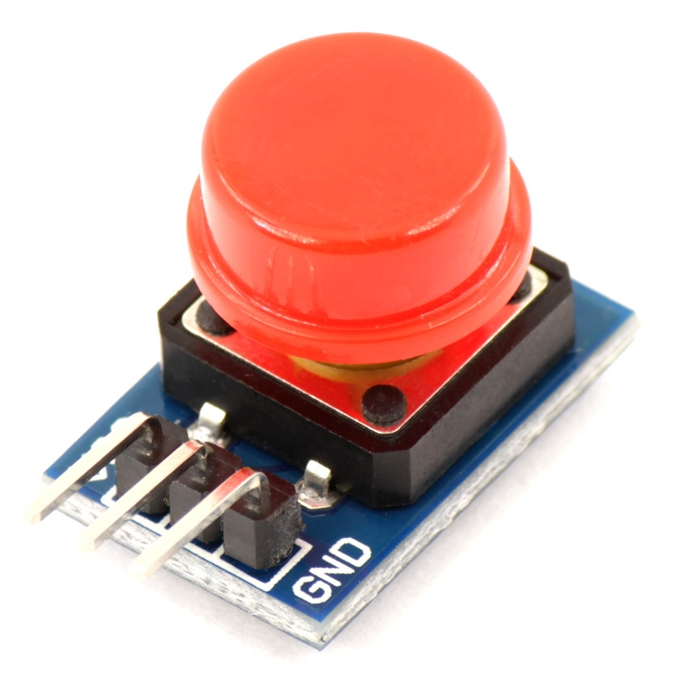
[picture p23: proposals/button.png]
Button
| Some amount of words from [SLIP39 wordlist](https://github.com/satoshilabs/slips/blob/master/slip-0039/wordlist.txt) | Rotary-Encoder(or Wheel) + Buttons<br/>Buttons<br/>:heavy_plus_sign:<br/> | Each word will define an index in wordlist, other words - a number [0 - 1023]. Such several indexes will give more long number then just PIN.<br/>:+1: can be used across all devices because SLIP39 is open standard<br/>:heavy_minus_sign: it'll be difficult to navigate between 1024 wordlist to choose needed...  |
| PIN | - | PIN board<br/>4x4 matrix keyboard | :+1: easy to type digits<br/>:-1: can type only digits<br/>:-1: size is not minimalistic |
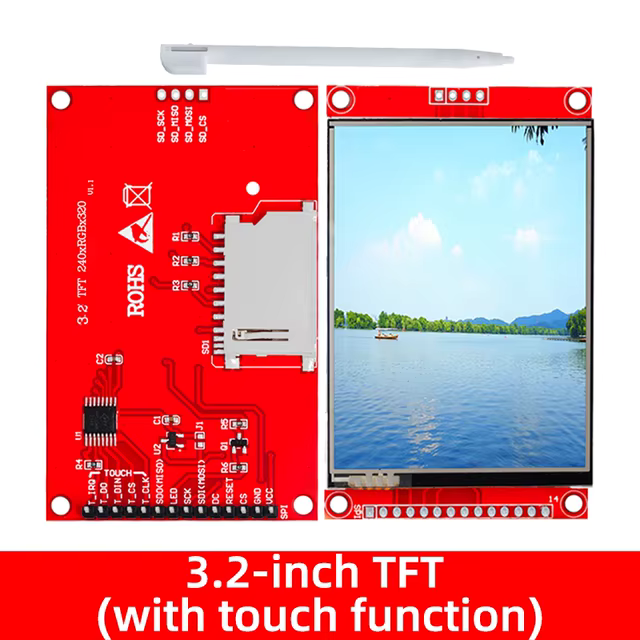
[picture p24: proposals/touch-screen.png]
3.2 inch touch LCD
| Password, PIN | - | Touch LCD 3.2 inch<br/> | :+1: UI freedom - any buttons, text, etc.<br/>:-1: in 2-3 times more expensive then encoder + buttons |
| Password, PIN | - | Touch LCD 2.4 inch (71x52mm)<br/>2.4 inch touch LCD | :+1: UI freedom - any buttons, text, etc.<br/>:+1: price is similar as buttons + encoder<br/>:+1: enough small size<br/>? how hide from foreign eyes?<br/>:-1: development complexity increase significantly<br/>more simple components schema |
| PIN | - | Rotary-Encoder(or Wheel) + Buttons<br/>Buttons<br/>:heavy_plus_sign:<br/>Rotary Encoder | <br/>:+1: no additional equipment<br/>:+1: theoretically it's possible to do that by one hand<br/>:-1: non minimalistic device size |
| PIN via typing Morse code | Pushing one button typing using Morse code | Button<br/>Button | :+1: less buttons will be needed<br/> :-1: only digits are available<br/>:-1: modern User does not know Morse code |
| Password via typing Morse code | Pushing one button typing using Morse code | Button<br/>Button | :+1: less buttons will be needed<br/> :-1: only digits and alpha are available<br/>:-1: modern User does not know Morse code |
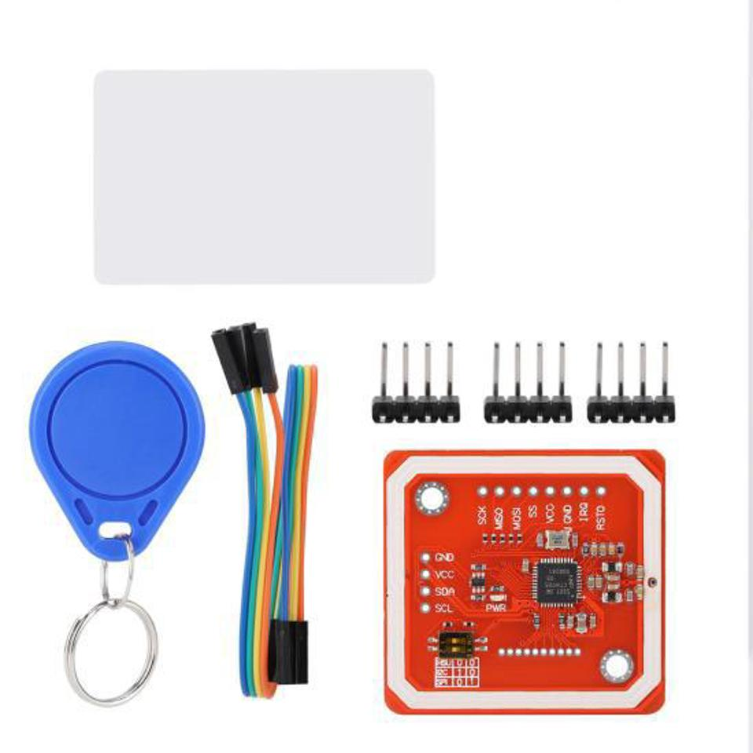
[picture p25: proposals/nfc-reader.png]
NFC Reader
| ISO14443 Card | Card | NFC reader<br/> | :-1: may be stolen together with CredsHolder. Can be used as 2FA. |
| OTP | Separate OTP device/application | PIN board<br/>4x4 matrix keyboard | :+1: only digits are needed<br/>:-1: how generate KEK if passwords is one time use?<br/>:-1: separate device/app is needed |
| Biometric. Voice | Voice | Microphone<br/>Microphone module | :-1: Need voice recognition AI and consequent requirements for Controller |
| Biometric. Fingerprint | Finger | Fingerprint scanner<br/>Fingerprint Sensor | :-1: difficult to say how difficult to trick cheap scanner<br/>:-1: high price |
| Biometric. Eye | Eye | Eye scanner | :-1: if eye is compromise then only 2nd one is available |
| Biometric. Palm vein pattern | Arm | Palm vein scanner | :-1: expensive<br/>:-1: size |
| Biometric. Mind (Sci-Fi) | Human Brain Human Brain

### What User should remember or have?

So if shortly we may use next to prove ownership: Password, PIN, Biometric, 2FA or their combinations.
* Password
* PIN
* Biometric
* 2FA (RFC card)
* SLIP39 words

#### Password

Password is used in projects:
* [Pastilda Sources](https://github.com/thirdpin/pastilda)
* RecZone Password Safe

:heavy_plus_sign: Give better protection for bruteforce attacks if use non-digit symbols too.

#### PIN

PIN is used in:
* [Trezor Wallet](https://trezor.io/)
* [Mooltipass](https://www.themooltipass.com/)
* [PasswordPump](https://github.com/seawarrior181/PasswordPump)
* [PasswordPumpII](https://www.5volts.org/post/passwordpump-v2-0)
* [Istorage DatAshur](http://www.byte-on.ru/catalog/Istorage-DatAshur/fleshka_istorage_datashur_pro_16gb/)
* Chipdrive MyKey

From [Trezor Wallet site](https://trezor.io/learn/basics/what-is-a-hardware-wallet):
```
Security and PIN protection
A key security feature is PIN protection, which allows you to secure your Trezor with a PIN up to 50 digits long. This provides quick access to your private keys as long as you have the device. If the device is lost, unauthorized access is incredibly unlikely—after each incorrect PIN attempt, the waiting time doubles, and after 16 failed attempts, the device is wiped automatically.
```

From [Trezor Firmware GitHub](https://github.com/trezor/trezor-firmware/tree/main/storage#pin):
```
The PIN is not stored in the flash storage. An entry is added to the flash storage consisting of a 256-bit encrypted data encryption key (EDEK) followed by a 128-bit encrypted storage authentication key (ESAK) and a 64-bit PIN verification code (PVC). The PIN is used to decrypt the EDEK and ESAK and the PVC is used to verify that the correct PIN was used. The resulting data encryption key (DEK) is then used to encrypt/decrypt protected entries in the flash storage. We use Chacha20Poly1305 as defined in RFC 7539 to encrypt the EDEK and the protected entries. The storage authentication key (SAK) is used to authenticate the list of (APP, KEY) values for all protected entries that have been set in the storage. This prevents an attacker from erasing or adding entries to the storage.

PIN verification and decryption of protected entries in flash storage

1. From the flash storage read the entry containing the random salt, EDEK and PVC.

2. Gather constant data from various system resources such as the ProcessorID (aka Unique device ID) and any hardware serial numbers that are available. The concatenation of this data with the random salt will be referred to as salt.

3. Prompt the user to enter the PIN and compute:

PBKDF2(PRF = HMAC-SHA256, Password = pin, Salt = salt, iterations = 10000, dkLen = 352 bits)

The first 256 bits of the output will be used as the key encryption key (KEK) and the remaining 96 bits will be used as the key encryption initialization vector (KEIV).

Note: Since two blocks of output need to be produced in PBKDF2 the total number of iterations is 20000.

...

```
From [Mooltipass Firmware GitHub](https://github.com/mooltipass/minible#the-mooltipass-devices):

```
All Mooltipass devices (Mooltipass Standard, Mooltipass Mini, Mooltipass Mini BLE) are based on the same principle: each device contains one (or more) user database(s) AES-256 encrypted with a key stored on a PIN-locked smartcard. 
```

#### Biometric

:heavy_minus_sign: more expensive components
:heavy_minus_sign: dependency on devices internal non OpenSource implementation
:heavy_minus_sign: using biometric increases chance that Intruder will cut part of User's body to unlock CredsHolder (((

#### 2FA (RFC card)

:heavy_minus_sign: Maybe stolen together with CredsHolder

Maybe it's possible variant for Corporate where ISO14443 cards is widely used by employees for identification.

#### SLIP39 words

Each word from [SLIP39 wordlist](https://github.com/satoshilabs/slips/blob/master/slip-0039/wordlist.txt) means an index in that wordlist, so it's a number at diapason [0 - 1023].

Such several numbers will give more long number then PIN.

:+1: can be used on new device if original is broken because SLIP39 is open standard

:heavy_minus_sign: I'm afraid that navigation among 1024 words will be equal to Password typing

This idea may be postponed upon good idea for navigation.

### Proposal 1. Let's use PIN

According to information above the PIN is widely used in similar projects, and in smartphones and so on.

| Proposal 1 |
| --- |
| Let's assume that PIN is enough good for authenticate User. |
| It must be not possible to decrypt application data on extractable CredsHolder storage knowing PIN only.<br/>Otherwise bruteforce will help Intruder.<br/>It means that "salt" MUST depend on concrete Controller identity - ProcessID, ... | 

Minimal PIN length will be known after finish [CredsHolder Storage Design](./creds-holder-storage.md)

## What about Intruder threat?

We must take into account not only usability of CredsHolder interface but also outside conditions - Intruders spying on User. Therefore we may assume that all sequence of manipulations, pushes, clicks made by User during authentication is known by Intruder, e.g. he used video camera to record whole process.

We need to make "sequence of typed digits" less usable.

Proposals: 

* User types PIN not in sequential way - 1st digit, 2nd one, 3rd one, etc. - but in random sequence, e.g. 8th digit, 3rd one, 1st one, 6th one, etc. CredsHolder will require User to do that (see screens below) |
* Not allow to record display with password or not use display at all |

| :warning: |
|---|
| Good random generator is needed ! |

Example of Authentication procedure screens:
```
+-----------------+
| Enter PIN:      |
|                 |
| ..2...         |
+-----------------+
       ||
       \/
+-----------------+
| Enter PIN:      |
|                 |
| 1.*...          |
+-----------------+
       ||
       \/
+-----------------+
| Enter PIN:      |
|                 |
| *.*.5.          |
+-----------------+
       ||
       \/
+-----------------+
| Enter PIN:      |
|                 |
| *4*.*.          |
+-----------------+
       ||
       \/
+-----------------+
| Enter PIN:      |
|                 |
| ***9*.          |
+-----------------+
       ||
       \/
+-----------------+
| Enter PIN:      |
|                 |
| *****7          |
+-----------------+
```

### Proposal 2. Non recognizable PIN

TRIZ Ideal Final Result:
* During authentication procedure User is typing PIN but used digits are not recognizable by visual observation

#### PIN keyboard

4x4 matrix keyboard

Buttons has titles - 0, 1, 2, .., <br/>BUT they must mean another digits, changing randomly for each PIN position:<br/>for example,<br/> 0245791386 for 1st one,<br/> 8194275360 - for 2nd one and etc.

Option 1. Will work for virtual keyboard on touch LCD screen. There we may print any digits on buttons.

Option 2. Yes, buttons will mean random digit, User will push them all one by one finding needed and push separate button to confirm entering digit.

#### Rotate Encoder + Buttons

Buttons:heavy_plus_sign:Rotary Encoder

CredsHolder suggests digits to type into PIN position not in regular sequence 0, 1, 2, .., 9 but randomly, e.g. 3, 5, 4, ...<br/>BUT user should see on display suggested digits.

If display will be protected Intruder will cannot even recognize digits from video record of authentication.

#### Voice recognition using wireless laryngophone with bone conduction

Laryngophone

Laryngophone with bone conduction has one big advantage - voice is listen by CredsHolder but not by outside people or spy equipment.

User can make voice command to device in all scenarios, not only during authentication.

:heavy_minus_sign: expensive
:heavy_minus_sign: higher requirements for Controller

#### Position sensor

Required to install: position sensor and vibration motor

User will lean CredsHolder forward to scroll digit up and lean CredsHolder down to scroll digit down.

CredsHolder will vibrate on recognition movement with device made by User.

CredsHolder suggests digits to type into PIN position not in regular sequence 0, 1, 2, .., 9 but randomly, e.g. 3, 5, 4, ...<br/>BUT user should see on display suggested digits.

:heavy_minus_sign: BUT display is needed.

If display will be protected Intruder will cannot even recognize digits from video record of authentication.

:heavy_minus_sign: :heavy_plus_sign: Unknown influence on defencing screen from outside watch during active moving CredsHolder... 

#### Conclusion

Suggestions are good. Let's wait design for navigation to choose someone.

Let's calculate a chance to guess PIN if Intruder knows used digits but not their sequence:
* Intruder knows the used symbols because recorded typing process
* Intruder does not know sequence of that symbols
* So there are N! possible combinations ...
* ... and only 10 fail tries before CredsHolder full-block/erasing/etc.
* Therefore chance is 10/(N!), e.g. for N=6: `10/(N!) = 10/(1*2*3*4*5*6) = 0.01389 = 1.389%`

### Proposal 3. Invisible display

TRIZ Ideal Final Result: 
* CredsHolder/display during authentication procedure will not allow Intruder to recognize PIN typing by User.
* CredsHolder does not use display during authentication but User can type PIN.

#### Entities

* Case
* Display
* Buttons
* Controller
* Possible additional components - vibration module, LEDs, microphone, audio output, etc.
* User (arms, senses)
* Air outside CredsHolder
* Lightness outside CredsHolder
* Position of CredsHolder in space

It's reasonable to do some trick only during authentication and after unlocking usage will be as usual.

Possible variants:

#### PIN via listen Morse code

Used inputs:

Button:heavy_plus_sign:Vibration Motor Module

Display will not show password typing or print how many digits has been entered.

* CredsHolder has vibration module
* CredsHolder vibrates position of PIN digit using Morse code
* then CredsHolder vibrates

| Digit | Morse code |
| --- | --- |
| 1 | :black_circle: :heavy_minus_sign: :heavy_minus_sign: :heavy_minus_sign: :heavy_minus_sign: |
| 2 | :black_circle: :black_circle: :heavy_minus_sign: :heavy_minus_sign: :heavy_minus_sign: |
| 3 | :black_circle: :black_circle: :black_circle: :heavy_minus_sign: :heavy_minus_sign: |
| 4 | :black_circle: :black_circle: :black_circle: :black_circle: :heavy_minus_sign: |
| 5 | :black_circle: :black_circle: :black_circle: :black_circle: :black_circle: |
| 6 | :heavy_minus_sign: :black_circle: :black_circle: :black_circle: :black_circle: |
| 7 | :heavy_minus_sign: :heavy_minus_sign: :black_circle: :black_circle: :black_circle: |
| 8 | :heavy_minus_sign: :heavy_minus_sign: :heavy_minus_sign: :black_circle: :black_circle: |
| 9 | :heavy_minus_sign: :heavy_minus_sign: :heavy_minus_sign: :heavy_minus_sign: :black_circle: |
| 0 | :heavy_minus_sign: :heavy_minus_sign: :heavy_minus_sign: :heavy_minus_sign: :heavy_minus_sign: |

#### CredsHolder speak digits via wired or wireless headset

If CredsHolder has audio out then can pronounce digits to User via headset.

:heavy_minus_sign: Difficult to use when high noise everywhere, e.g. in server room.

#### Display with Braille cipher

Separate display which may show digits as a dots in Braille cipher. User should touch it by fingers and recognize suggested digit.

:heavy_minus_sign: very specific, low usability
:heavy_minus_sign: expensive

#### OLED is hidden in case and covered by anti spy glass

Hidden display

### Proposal 4. Delay between fail tries

* CredsHolder remember amount of fail tries on plugging out from User device
* CredsHolder is fully locked between fail tries for in 2 times more period then previously
* CredsHolder will erase data after N fail tries (must be set in configuration)
* CredsHolder do not allow enter the same false PIN twice to avoid lost try

| Reason |
|---|
| If you'll be able find/return CredsHolder then you'll be able to try unlock in very long period during which it'll be unusable for you.<br/>Make backup regular. |

### Proposal 5. Log out

TRIZ Ideal Final Result: 
* CredsHolder lock itself when become unneeded for User

Proposals:
* User may log out explicitly.
* Auto-logout after some period without User activity. It's a backup for case when User forgot to lock CredsHolder.
* Logout if User turn CredsHolder upside down
* Logout if User dropped the device

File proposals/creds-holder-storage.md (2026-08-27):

<!--
Copyright (C)  2026  Ivan Efimov aka MuteSpirit <mutespirit@yandex.ru>.

Permission is granted to copy, distribute and/or modify this document
under the terms of the GNU Free Documentation License, Version 1.3
or any later version published by the Free Software Foundation;
with no Invariant Sections, no Front-Cover Texts, and no Back-Cover Texts.
A copy of the license is included in the section entitled "GNU
Free Documentation License".
-->

# CredsHolder Storage

## Introduction

This document is related to full chain and all places of securely storage settings and application data by CredsHolder.

## Abbreviations and Terms

* EEPROM -
* FW - firmware
* FAT16 -
* FIDO2 -
* WebAuthn -
* MEK - Media Encryption Key
* KEK - Key Encryption Key
* PIM - Personal Iteration Multiplier
* KDF - Key Derivative Function
* MCU - Microcontroller Unit (CPU + EEPROM + RAM + peripherals = MCU)

## Requirements

If shortly a lot of requirements below says next:
* CredsHolder MUST store information interested for me (credential accounts, OTP, etc.)
* If CredsHolder is broken then I may take another CredsHolder and continue use my account on it
* If I lost CredsHolder then nobody access my data
* I'm able to make CredsHolder backup

| No | User Story |
| --- | --- |
| S-2 | As an User I'd like to use hardware credential manager CredsHolder to store personal accounts only. |
| S-3 | As an User I'd like to use CredsHolder with any of devices: desktop PC, laptop, smartphone, tablet. |
| S-5 | As an User I'd like to store about 1000 accounts on CredsHolder. |
| S-6 | As an User I'd like that CredsHolder has less vulnerabilities as possible. |
| S-9 | As an User I'd like be able easy replace CredsHolder with full credentials migration to new CredsHolder if the current one is broken or User bought more modern CredsHolder model. |
| S-10 | As an User I'd like be sure that my credentials will be not compromised if CredsHolder is stolen by Intruder. |
| S-12 | As a Corporate Employee I'd like to use CredsHolder to store work accounts credentials. CredsHolder MUST all Corporate security standards. |
| S-15 | As a Governmental Employee I'd like to use CredsHolder to store work accounts credentials. CredsHolder MUST follow the related governmental security standards and laws in spite of backdoor in cipher and hashing algorithms added by Government. |
| S-16 | As a Developer I'd like that CredsHolder become widely usable all over the world. |
| S-17 | As a User I'd like to avoid vendor lock because Vendor may bankrupt or increase tariffs or block support for owner country and so on. |
| S-18 | As a User I'd like to change authentication key (master password, etc.) if it was vulnerable. |
| S-20 (optional) | As a User I'd like to allow inherit my CredsHolder by my inheritors after my death. |
| S-21 | As a User I'd like to able make CredsHolder backup. |

| No | Re User Story | Requirement |
| --- | --- | --- |
| R-3 | S-2 | CredsHolder MUST store Account Credentials. |
| R-4 | S-2 | CredsHolder SHOULD store OTP Credentials. |
| R-10 | S-5 | CredsHolder MUST support navigation between Account Credentials.<br/>It may be done like listing them one by one.<br/>It may be done like groups hierarchy<br/>It may be done like full text search.<br/>It may be done like priority queue with accounts where last used ones are located in the queue head. |
| R-11 | S-5 | CredsHolder MUST have enough Persistent Storage for 1000 Account Credentials. |
| R-12 | S-5 | CredsHolder MUST allow easy way to manage Accounts (add/delete/change). |
| R-18 | S-6, S-17 | CredsHolder MUST store Accounts Credentials inside and do that without using separate application or Cloud storage. |
| R-19 | S-6 | CredsHolder MUST keep into account that "power cut" may happen at any time. |
| R-23 | S-10 | Application Data must be encrypted and independent on data at CredsHolder internal data |
| R-24 | S-10 | CredsHolder MUST authenticate User before grand access to application data. |
| R-25 | S-10 | If User assumes that CredsHolder cannot be stolen then it should be able to turn authentication off. So ownership of CredsHolder will mean passed authentication. |
| R-27 | S-10 | CredsHolder SHOULD have some schema to erase/block/hide credentials from Intruder if both CredsHolder and User will be stolen. |
| R-30 | S-15 | CredsHolder code/FW MUST allow to extend encryption/hash algorithm and add something else. |
| R-31 | S-16 | CredsHolder SHOULD print owner contact (:question: and name :question:).<br/>If owner lost device and someone find it, device itself will help to return it back to owner |
| R-34 | S-16 | CredsHolder License MUST allow commercial usage to allow any company make and sale CredsHolder based product. |
| R-39 | S-18 | CredsHolder MUST allow to change "master password" (or it's analog). |
| R-40 | S-21 | CredsHolder MUST allow backup/restore application data/settings. |
| R-41 (optional) | S-19 (optional) | CredsHolder MUST allow password authentication. Maybe like alternative method. |
| R-42 (optional) | S-20 (optional) | CredsHolder MUST support several passwords for authentication. Or another several "master password" analogs, e.g. fingerprint, to allow notary to unblock CredsHolder.<br/>Even more better if both fingerprints/passwords - of inheritor AND notary are needed to unblock CredsHolder |

## Background

### What to store?

Let's find out what information store another similar projects:

| Project | Storage, File System | Data on board |
| :---: | :---: | :---: |
| [DIY USB password generator](https://codeandlife.com/2012/03/03/diy-usb-password-generator/) | Internal EEPROM, no FS, no encryption | Single password |
| [DYI HW Single Password Manager](https://habr.com/p/827616/) | Internal EEPROM, encryption | Single password |
| [Pastilda](https://www.crowdsupply.com/third-pin/pastilda) | microSD Card, FAT16, encryption | Encrypted KeePass 2.x database (.kdbx file) and the KeePass 2.x portable app as needed. |
| [Crypto Kakadu](https://vk.ru/cryptokakadu) | Unknown |
| [PasswordPump](https://github.com/seawarrior181/PasswordPump) | external EEPROM chip 25LC256, no FS, encryption | Credential accounts double-linked list in raw format on EEPROM |
| [PasswordPumpII](https://www.5volts.org/post/passwordpump-v2-0) | external EEPROM chip 25LC512, no FS, encryption  | Credential accounts, groups |
| [Mooltipass](https://www.themooltipass.com/) | SmartCard with key, microSD Card, no FS but [custom flash layout](https://github.com/mooltipass/minible/wiki/Mooltipass-Database-Model#-user-profile-and-db-flash-layout), encryption | Passwords, FIDO2, WebAuthn & Passkeys, Files & Notes<br/>graphic elements, FW upgrades<br/>[Own DB format](https://github.com/mooltipass/minible/wiki/Mooltipass-Database-Model):<br/>* Multiple doubly linked list-based credential and file storage<br/>* Parent (services) - Child (credentials) structure<br/>* Credential categories support<br/>* Credential favorites support<br/>* Webauthn custom credential type<br/> At the time of writing, the Mini BLE can handle logins & passwords up to 64 unicode characters long. |
| [Trezor Wallet with Secure Element](https://trezor.io/) | Secure Element | Crypto currency private key(s) |
| [Trezor Wallet without Secure Element](https://trezor.io/) | internal flash, no FS, own layout ([Trezor Wallet Storage Implementation](https://github.com/trezor/trezor-firmware/blob/main/docs/core/embed-arch/embed-arch.md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)), encryption | Crypto currency private key(s) |
| [Ledger Crypto Wallet](https://www.ledger.com/) | Secure Element | Crypto currency private key(s) |
| [Mew](https://github.com/konachan700/Mew) | | Passwords, Crypto Wallet |
| RecZone Password Safe | external EEPROM chip, NO encryption - see [Hardware Access To EEPROM chip on RecZone Password Safe](https://github.com/jackquavis/Recovering-Reczone-Password-Safe-Passwords) | Passwords |

### What to backup?

Because Ledger and Trezor wallets use hierarchical deterministic key generation they do not store information which must be backup or migrated to new device in digital view, the physical BIP39/SLIP39 backup will be enough to start use new device and restore access to your coins in blockchain:
* From [Ledger Crypto Wallet "The Master Seed" documentation](https://developers.ledger.com/docs/device-app/explanation/psd/masterseed):
```
 Ledger achieves both of these goals by using hierarchical deterministic key generation. Hierarchical deterministic key generation is used by applications to derive a theoretically infinite number of cryptographic secrets from a single master seed. This way, your cryptocurrency private keys, passwords, and other cryptographic secrets can all be determined and intrinsically “stored” in a single master seed. Thanks of this, the device’s apps don’t have to store their own private keys, because they can all be generated on-demand by the device from the master seed. This means that if your device is lost, destroyed, or reset then all you need is your master seed to recover your secrets. In addition, an application that supports this scheme can be deleted and reinstalled without losing any secure data or assets. Your master seed is randomly generated for you when you first set up your Ledger device, and then you just need to write it down to allow you to recover your device in the future.
```
* Trezor Crypt Wallet [follow the same BIP39 and SLIP39 standards](https://trezor.io/guides/backups-recovery/general-standards/how-to-use-a-wallet-backup) for backup:

```
Your wallet backup may also be referred to as a: backup, Single-share Backup, Multi-share Backup, recovery seed, seed, seed phrase, BIP39 phrase, SLIP39 phrase, mnemonic, recovery phrase (plus various combinations of these terms).
It is an ordered list of English words that contains all information necessary for recovering your wallet (i.e., accessing Bitcoin or other cryptocurrency funds on-chain).
A wallet backup provides full access to the associated wallet. This is why you must keep it safe.
```

## Proposals

CredsHolder Storage

* CredsHolder has removable storage (on microSD card)
* Removable storage contains 2 partitions:
  * 1st partition (label "apps") containing portable VeraCrypt applications for Linux, Windows and macOS
  * 2nd partition (label "storage") is used as encrypted storage. It's minimal size MUST be 128 MB.
* 1st partition may be absent. It's up to User how and were store them.
* 2nd partition is formatted as VeraCrypt volume
* On first start CredsHolder:
  * Generate "Recovery Code" (alpha-digit password (MEK) + PIM)
  * Ask PIN from User
  * Create VeraCrypt on 2nd partition. Header is included.
  * Use PBKDF2 as KDF
  * Create KEK from PIN, PIM and MEK
  * Create LUKS header in internal memory and store KEK and PIM inside
* Backup procedure is cloning CredsHolder microSD card. So backup will be in encrypted form only.
* Restore procedure:
  * insert backup microSD card or card from another device
  * type "Recovery Code"
  * set new PIN
* Make brute-force attack more complex:
  * Use slowest hash function - Whirlpool at current moment
  * Use non standard PIM to make it an additional variable for brute-force attack
  * Use function to derive key which work constant time. That will not allow to guess amount of PIM

See all details how conclusion above has been designed in next sections.

## Contradictions

### Contradiction. Extract application data from device

* As an User I'd like be able easy replace CredsHolder with full credentials migration to new CredsHolder if the current one is broken or User bought more modern CredsHolder model ...
* But it's needed to extract all application data from Device
* And it SHOULD be done without additional equipment because User is not a geek in common

Proposal:
* Storage should be removable/pluggable.

Among similar projects there were two types of widely used removable flash:
* EEPROM chips in special SOIC8 to DIP8 programmer adapter
* microSD card

### Contradiction. Removed storage can be brute-forced

* CredsHolder storage SHOULD be removable
* But that will allow perform password brute-force infinitely.

IFR: device storage MUST defense itself from brute-force

Possible variants: LUKS, VeraCrypt or custom flash layout

### Contradiction. What should be encrypted

* Similar projects has several variants:
  * partially encrypted data on custom flash layout (Mooltipass, Trezor, PasswordPump)
  * encrypted password manager database file on partition with FAT (Pastilda)
* Also there is a User Story S-3 "As an User I'd like to use CredsHolder with any of devices: desktop PC, laptop, smartphone, tablet."
* And also it's complex to support custom flash layout especially extent it and no one supported on desktop/mobile OS

According to [wiki](https://en.wikipedia.org/wiki/Comparison_of_disk_encryption_software) only next OpenSource and still maintained projects are widely supported on many OSes:
* VeraCrypt is supported on all next OS: Android, Windows, iOS, Linux, MacOS, FreeBSD
* EncFS all above plus OpenBSD, FreeBSD, NetBSD

But the [EndFS wiki](https://en.wikipedia.org/wiki/EncFS) says about vulnerabilities in implementation.

I know that LUKS and VeraCrypt has documented volume header.

Proposal:
* Use VeraCrypt
* Separate abstraction layer for encryption
* Applications will use file on FS inside encrypted volume
* Applications will be independent on encryption
* We'll be sure that ALL data is encrypted on removable device
* Each Application (password manager, OTP manager) will be able to use different files and be developed independently

:+1: it'll be easier to develop application on host PC because it'll be used technologies available not only for embedded systems.

### Contradiction. Where take PIM

* VeraCrypt volume header does not contain PIM
* But it's needed for decryption

Proposal:
* Store in internal flash
* Make PIM a part of "Recovery Code"

### Contradiction. PIN is too short

* An unplugged storage will allow perform password brute-force infinitely
* And encryption algorithm and hash function is known from CredsHolder sources
* And enough long and complex password is needed to defense encryption on storage
* And non default PIM
* But User can remember and use daily enough short PIN which therefore is not usable as password

From [Trezor Storage when Secure Element is absent](https://github.com/trezor/trezor-firmware/tree/main/storage#design-rationale):
```
The purpose of the PBKDF2 function is to thwart brute-force attacks in case the attacker is able to circumvent the PIN entry counter mechanism but does not have full access to the contents of the flash storage of the device, e.g. fault injection attacks. For an attacker that would be able to read the flash storage and obtain the salt, the PBKDF2 with 20000 iterations and a 4- to 9-digit PIN would not pose an obstacle.
```

By the way, both VeraCrypt and LUKS encrypted header contains salt but LUKS header also contains a name of encryption algorithm and PIM also. That decrease brute-force complexity and that is one more reason no use LUKS on removable storage,

#### Proposal. Use PIN as password

* Keep encrypted volume header on internal memory instead of removable storage
* Store PIM at internal memory
* BTW, [VeraCrypt Volume Format Specification](https://veracrypt.io/en/VeraCrypt%20Volume%20Format%20Specification.html) shows that only salt is not encrypted, others is encrypted.

Rejected because:
* :heavy_minus_sign: Backup procedure must be coded separately to allow User to initial recovering encrypted volume header on removable storage. That header will be erased automatically on next CredsHolder turning on
* :heavy_minus_sign: Anyway there will be a time when removable storage will contain encrypted partition header where enough easy PIN is used as password. That period is vulnerable.
* :heavy_minus_sign: PIM is still needed to informed to User to be able perform recover procedure

#### Proposal. "Use removable smart card and removable storage"

* Like [Mooltipass do that](https://www.themooltipass.com/)
```
The Mooltipass devices all use a PIN-locked smartcard containing the AES-256bits key required for data decryption. Like any chip and pin card, 3 false tries will permanently disable the Mooltipass card.

...

- Device Design - What if I lose my Mooltipass device?

Your encrypted credentials can be exported to your computer. If you lose your device, you may purchase another one and restore your credentials or buy a simple inexpensive smartcard reader to extract your encryption key and decrypt your credential database.

...

- Device Design - What if I lose my smartcard?

Our device is shipped with two smartcards, so you can keep a copy somewhere safe. The Mooltipass allows the user to clone their smartcard as many times as they want, provided that the card PIN is correctly entered.
```
* :+1: PIN protection is on smart card side
* :+1: encryption key is not extractable and known to nobody
* :heavy_minus_sign: smart card and it's reader is needed inside CredsHolder, separate smart card reader is needed for User to make clone(s) of smart card installed in device
* :heavy_minus_sign: two cards are needed instead of one plus knowledge of "Recovery Code"
* :heavy_minus_sign: we are limited in policy of blocking device by smart card hardware
* :heavy_minus_sign: smart card code is proprietary with unknown amount of vulnerabilities

#### Proposal. "Use RFID card together with PIN"

:heavy_minus_sign: easy to lost
:heavy_minus_sign: will be always together with CredsHolder and will be stolen together

#### Proposal. "PIN for human and password for encryption"

* Keep header on removable storage - Intruder will know salt but not password and not PIM
* Use strong MEK - generate before create encrypted storage 1st time
* Show MEK and PIM as "Recovery Code" to User and highly recommend to remember
* Generate KEK: Use PBKDF2 with PIN as password with separately generated separate KEK salt and KEK PIM.
* Encrypt MEK with PBKDF2 output, result will be KEK. Store that at internal memory only.
* On regular usage when User unlocking device run PBKDF2 with PIN to get KEK and decrypt MEK to decrypt data on removable storage
* It's possible to use LUKS header format at internal storage to support several KEK and maybe reuse exist code supporting LUKS

* :+1: On device break you need ask User about "Recovery Code" (it's MEK) and recreate KEK at internal memory
* :+1: That will allow to use VeraCrypt which has no support for several password slots but supported on all OS (Windows, Linux, macOS). That will allow to decrypt removable storage on PC
* :+1: It's not needed to make backup as separate procedure which recover LUKS/VeraCrypt header on removable storage. User is able to make copy of removable device on PC at any time. It'll be save to store backups as digital copies.
* :heavy_minus_sign: on recovering access to storage it'll be needed to enter that long complex "Recovery Code"

### Contradiction. Complex "Recovery Code"

"Recovery Code" is complex to type during recovery procedure AND it's difficult to remember it

IFR:
* "Recovery Code" must itself be easy to remember
* Element X without increasing system complexity during recovery procedure on device keep "Recovery Code" easy to remember
* Recovery procedure must itself provide comfortable way to type "Recovery Code"

Proposal:
* Use only digits and lowercase alpha in MEK
* Use non standard PIM and make it part of "Recovery Code"

### Contradiction

* KEK derived from PIN is kept in internal memory
* But if Intruder extract it then brute-force will be easy

IFR: Controller defense itself from extraction data from internal memory

Proposals:
* Use "Secure Boot"
  * nrf52840 has "nRF Secure Immutable Bootloader (NSIB)" suggested by Nordic Semiconductor SDK
  * STM32U5 and STM32WB35 has hardware capabilities for Secure Boot
* "non extractable bootloader" as a root of trust chain will prevent burn not-signed bootloader/firmware which may extract encryption

### Contradiction

* CredsHolder storage is VeraCrypt encrypted partition
* And it cannot be mounted as-is on PC
* But there is a User Story S-3 "As an User I'd like to use CredsHolder with any of devices: desktop PC, laptop, smartphone, tablet."

IFR: CredsHolder storage itself allow to mount itself

Proposals:
* Removable storage contains 2 partitions:
  * 1st partition (label "apps") containing portable VeraCrypt applications for Linux, Windows and macOS
  * 2nd partition (label "storage") is used as encrypted storage

### Contradiction. What FS to use inside encrypted volume

* Different OS support not all file systems
* But there is a User Story S-3 "As an User I'd like to use CredsHolder with any of devices: desktop PC, laptop, smartphone, tablet."
* And exFAT and FAT32 is not tolerant for unexpected extraction flash drive
* From another side Controller code will fully control writing data to flash
* So it's unclear what FS to use

Let's try to write on flash without caching.

### Contradiction. Unexpected power cut tolerance

* VeraCrypt is caching data and do not write them directly
* When volume will be unexpectedly extracted then it will become unreadable
* Or file system inside become broken
* Or modifying file become broken

Let's try to write on flash without caching.

### Contradiction. What do KDF use?

* There is a recommendation to use Argon2 KDF instead of PBKDF2 to make brute-force more complex even with GPU use
* But Argon2 uses a LOT of memory, boards like Arduino, nrf52840 and STM32 does not have so much

Proposal:
* Continue PBKDF2 because it consumes small amount of memory
* That's a hardware limitation for us
* Maybe in future more powerful MCU will be able to use Argon2

### Contradiction. microSD of minimal size

CredsHolder needs size for application data.

There is R-11 "CredsHolder MUST have enough Persistent Storage for 1000 Account Credentials."

Each account is up to 694 bytes ~= 768 bytes:

* Account Name - 64 bytes
* login - 32 bytes
* password - 32 bytes
* URL of resource - no official limit, assume 255 bytes
* email - 254 bytes
* phone number - 12-16 symbols
* previous password - 32 bytes
* used password generation policy - 1 byte
* expiration date/time - 8 bytes

1000 accounts equal 768000 = 750 kB - much less then amount of partition for VeraCrypt portable applications.

Let's assume that in future we'll support TOTP, maybe notes, files, etc. Anyway they will use a small bytes in comparison to VeraCrypt portable applications.

VeraCrypt volume format has been choosen to be able insert microSD from CredsHolder, mount VeraCrypt volume on host PC and read (maybe modify) needed passwords.
Yes, it's opening password in plain view on PC which may be theoretically infected but in urgent situation when CredsHolder was broken but passwords are needed right now, it's enough good variant.

At 15 Aug 2026 the portable apps for Windows, Linux and MacOS has summary size 102.4 MB ~= 100 MB.
Let's assume that applications for Android, iOS and BSD has similar size and multiply in 2 times.
And assume that size of that application may grow in new versions and multiply in 2 times again.
And assume that new operation systems may appear in future and multiple in 2 times one more time.

And as a result it's needed: 100 * 2 * 2 * 2 = 800 MB. Let's round up to 1GB for application files.

So we have requirements contradiction:

* As a User I'd like to use microSD card in CredsHolder with minimal size to decrease device cost
* And make a CredsHolder backup of minimal size to keep space on backup storage
* But it's needed to store application data (less 5Mb) to perform CredsHolder main function
* And store VeraCrypt portable applications which may be needed never or at rare urgency case

The same as conditions contradiction:
* microSD card must be small to be cheap and easy to clone as backup
* And at the same time it must be enough big to store VeraCrypt application too

| No | Details |
| Option 1 "Download yourself" | We may try to assume that VeraCrypt portable applications are always available via Internet and User may download them on demand.<br/> But according to Murphy's law they will be needed at the moment of unavailable Internet access or equipment for that or permissions, or VeraCrypt site will be closed at that moment and applications are not available at all. |
| Option 2 "Second microSD Card" | Attach to device the 2nd microSD with needed application. It will be not plugged even, just attached to case. |
| Option 3 "Separate partition on main microSD" | Separate microSD will be more expensive then main microSD card with bigger size. Add separate partition for VeraCrypt portable applications |
| Option 4 "Let User to solve" | Let's add a requirement that partition with label "storage" must be present on microSD and has size at least 128 MB. <br/>CredsHolder will interpret it as VeraCrypt volume with own data.<br/>And CredsHolder will be tolerant to size of microSD card and other partitions present on it. |
| Option 5 "Second microSD card reader" | Application data is on smaller microSD card inserted into 1st card reader<br/>VeraCrypt applications are on bigger microSD card inserted into 2nd card reader which is available for PC (maybe mounted and content may be read (?but no modified?))<br/>:heavy_minus_sign:If we are assume that in worst case CredsHolder device will be dead then it'll be not able to work as card reader |
| Option 6 "Share decrypted for PC" | Theoretically CredsHolder could be share content of encrypted volume for PC after unlocking, PC will be even not aware about encryption usage<br/>But if we take into account case of broken CredsHolder Then it'll not help |

Option 4 looks like compromise. We may create 2 different SD card images - with and without partition with VeraCrypt portable applications.

And one more conclusion - there are no reasons for CredsHolder to work as card reader and give access to microSD card for User's equipment to which it's attached to.

## Rejected Ideas

### Idea 1. BIP39/SLIP39

Crypto wallets uses BIP39/SLIP39 as backup to be able restore master seed and regenerate private keys using CKD function.

But it also means that master seed is a number which may be used as encryption password.

So we may randomly generate a'la master seed then convert it into 12 words, say them to user as backup.

We'll be able to do that at any time on unlocked CredsHolder.

:heavy_minus_sign: difficulty of showing sequence of many words to User, not sure how it'll be usable.

### Idea 2. Crypto card

Idea is a modification of [this idea](https://www.passwordcard.org/).

Create separate partition "crypto card" on microSD equal to 1024 * 32 bytes.

Fill them with random data.

Randomly choose 12 numbers from diapason [0-1024].

Use them as indexes and read 12 double-words (32 bytes) from "crypto card" partition.

That will be an encryption password.

As a backup you may inform User a 12 indexes as numbers or words from BIP39 wordlist.

If someone will try to find encryption password among "crypto card" partition then in worst case he will check all combinations for 12 parts: C(1024,12) = 1024! / (12! × 1012!) = 2 601 150 623 552 800 702 891 545 856

:heavy_minus_sign: more complex variant then BIP39
:heavy_minus_sign: how easy enter 12 numbers/words from 1024 words list on small device like CredsHolder to recover access to device?
:heavy_minus_sign: how easy show 12 numbers/words on small device like CredsHolder for User to remember as backup?

## Links

* [Brute-force LUKS volumes](https://blog.elcomsoft.ru/2020/08/rasshifrovka-diskov-luks/)
* [Brute-force VeraCrypt volumes](https://blog.elcomsoft.ru/2020/04/rasshifrovka-kriptokontejnerov-veracrypt/)
* [VeraCrypt Volume Format Specification](https://veracrypt.io/en/VeraCrypt%20Volume%20Format%20Specification.html)

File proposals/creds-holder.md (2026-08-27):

<!--
Copyright (C)  2026  Ivan Efimov aka MuteSpirit <mutespirit@yandex.ru>.

Permission is granted to copy, distribute and/or modify this document
under the terms of the GNU Free Documentation License, Version 1.3
or any later version published by the Free Software Foundation;
with no Invariant Sections, no Front-Cover Texts, and no Back-Cover Texts.
A copy of the license is included in the section entitled "GNU
Free Documentation License".
-->

# HLD. CredsHolder

## Introduction

This document contains common design for hardware credential manager. The main goal is defining requirements and available entities of system.

The concrete parts of device and use case scenarios will be designed separately.

## Abbreviations and Terms

* Hardware Credential Manager - separate device which store credentials
* HLD - High Level Design (see [CONTRIBUTING.md](/CONTRIBUTING.md) for details)
* Device - the same as CredsHolder, the common title of current project device - hardware credential manager
* OS - Operating System
* DIY - Do It Yourself
* FW - firmware
* RTOS - Real-Time OS
* OTP - One Time Password

## Background

Similar hardware credential manager projects:

* [Pastilda](https://www.crowdsupply.com/third-pin/pastilda)
  * [Pastilda Sources](https://github.com/thirdpin/pastilda)
  * In common - very good project
  * :+1: Uses KeePass db file on storage
  * :+1: Use long password for authentication
  * :+1: USB connector adapters for ports on mobile devices
  * :-1: It's not obvious what mode - "pass through mode" or "Pastilda mode" is active now and at some time you will type you master password in "pass though mode" and some app on your PC accept it in electronic view
  * :-1: full keyboard is needed to work with mobile devices
  * :-1: no case
* [PasswordPump](https://github.com/seawarrior181/PasswordPump)
  * :-1: not stable UI/UX
  * :-1: too complex code for maintenance
  * :-1: no unit tests
  * :-1: weak security there is content encryption with AES-128 but ... 
    * master password salt is 2 bytes
    * PBKDF is not used, there is only one iteration to generate MEK from password
    * device is not protected from changing sketch, so salt and master password hash (PVC) maybe extracted from internal memory
    * not enough good random source - voltage on not plugged pin
* [PasswordPumpII](https://www.5volts.org/post/passwordpump-v2-0)
* [Trezor Wallet](https://trezor.io/) - OpenSource crypto wallet
* [Ledger Crypto Wallet](https://www.ledger.com/)
* [Mooltipath](https://www.themooltipass.com/)
  * [Mooltipath GitHub](https://github.com/mooltipass)
  * :-1: high price
* [DYI HW Single Password Manager](https://habr.com/p/827616/)
  * :-1: not OpenSource
* [Crypto Kakadu](https://vk.ru/cryptokakadu)
  * [Crypto Kakadu Apps](https://github.com/BTLabsru/crypto-kakadu)
* [Mew](https://github.com/konachan700/Mew)
* RecZone Password Safe
  * :-1: proprietary
  * :-1: cannot fill login forms
  * :-1: dead project
* [Table with links to next prjects](https://docs.google.com/spreadsheets/d/e/2PACX-1vSTtUPpAxm_SOiypDJNJfBNEZP4m8UpZj7Soh05UDWHxTOwhCkvwW8CD0Iu1X4dh2fK4I_Htv-Mjcp9/pubhtml)
  * [DIY USB password generator](https://codeandlife.com/2012/03/03/diy-usb-password-generator/)
  * [Istorage DatAshur](http://www.byte-on.ru/catalog/Istorage-DatAshur/fleshka_istorage_datashur_pro_16gb/)
  * Type4me
  * myIDkey
    * :-1: dead project
  * IDKEY
  * Password S-Crib
  * Usb2kbd
  * Memtype
  * MyLOK
  * Victorinox Slim
  * SplashID Key Safe
  * Chipdrive MyKey
  * APC Touch Biometric Pod
  * OnlyKey
  * Everykey
  * LogmeOnce
  * Password Reset Key
  * FIDO U2F Security Key
  * YubiKey 4

## Use Cases

### Actors

* Developer - project participant
* User - common CredsHolder user independent on his job
* Corporate Employee - User on job in non-governmental company
* Governmental Employee - User on job in governmental company
* Intruder - person who would like to use CredsHolder without User approval
* Vendor - commercial company manufacturing CredsHolder devices

### User Stories

| No | User Story |
| --- | --- |
| S-1 | As a Developer I'd like to make work as best as possible and add link to project into my CV. |
| S-2 | As an User I'd like to use hardware credential manager CredsHolder to store personal accounts only. |
| S-3 | As an User I'd like to use CredsHolder with any of devices: desktop PC, laptop, smartphone, tablet. |
| S-4 | As an User I'd like that CredsHolder will fill login form/prompt itself. |
| S-5 | As an User I'd like to store about 1000 accounts on CredsHolder. |
| S-6 | As an User I'd like that CredsHolder has less vulnerabilities as possible. |
| S-7 | As a Developer I'd like to develop new features for CredsHolder but Users will not have to buy to model to start use them. |
| S-8 | As an User I'd like to save some money and assemble/repair CredsHolder myself as DIY device. |
| S-9 | As an User I'd like be able easy replace CredsHolder with full credentials migration to new CredsHolder if the current one is broken or User bought more modern CredsHolder model. |
| S-10 | As an User I'd like be sure that my credentials will be not compromised if CredsHolder is stolen by Intruder. |
| S-11 | As an User I'd like be able use CredsHolder by one human arm, left or right. |
| S-12 | As a Corporate Employee I'd like to use CredsHolder to store work accounts credentials. CredsHolder MUST all Corporate security standards. |
| S-13 | As a Corporate Employee I'd like to use CredsHolder to login on corporate servers Web UI and in CLI/shell even in bootloader. |
| S-14 | As a Corporate Employee I don't trust build artifacts of public project I'd like to use on CredsHolder firmware components (sketch, certificates, etc.) built from sources or generated by Corporate |
| S-15 | As a Governmental Employee I'd like to use CredsHolder to store work accounts credentials. CredsHolder MUST follow the related governmental security standards and laws in spite of backdoor in cipher and hashing algorithms added by Government. |
| S-16 | As a Developer I'd like that CredsHolder become widely usable all over the world. |
| S-17 | As a User I'd like to avoid vendor lock because Vendor may bankrupt or increase tariffs or block support for owner country and so on. |
| S-18 | As a User I'd like to change authentication key (master password, etc.) if it was vulnerable. |
| S-19 (optional) | As a Corporate Employee I'd like to be able remotely unlock CredsHolder, e.g. one employee say password by phone to another employee. |
| S-20 (optional) | As a User I'd like to allow inherit my CredsHolder by my inheritors after my death. |
| S-21 | As a User I'd like to able make CredsHolder backup. |

### Requirements

Let's try to convert User Stories to more concrete (non)technical requirements.

Let's pay into account that CredsHolder has several stages in product life cycle:
* Designing/Development/Testing
* Manufacturing
* Usage
* Maintaining, Repairing
* Recycling, Resale

| No | Re User Story | Requirement |
| --- | --- | --- |
| R-1 | S-1 | Add all designs, code, unit tests, presentations and manuals. Work via TDD. :nerd_face: |
| R-2 | S-1 | CredsHolder SHOULD print project title and author on boot. |
| R-3 | S-2 | CredsHolder MUST store Account Credentials. |
| R-4 | S-2 | CredsHolder SHOULD store OTP Credentials. |
| R-5 | S-3 | CredsHolder MUST support Bluetooth connect to User equipment and battery power or ...<br/>has several USB connectors - USB-A, micro-USB, type-C male, - or universal connector to be able to attached to smartphone |
| R-6 | S-3 | CredsHolder MUST support Bluetooth connect to User equipment or ...<br/>has several USB connectors - USB-A, micro-USB, type-C male, - or universal connector to be able to attached to smartphone |
| R-7 | S-13 | CredsHolder MUST support USB connect to User equipment using USB-A connector.<br/> It's better to have universal connector - USB-A/USB-C |
| R-8 | S-3, S-4, S-13 | CredsHolder MUST emulate keyboard to fill login forms/prompt and avoid install special software/drivers.<br/>There are such protocols as FIDO2 but it's not supported in bootloader shell |
| R-9 | S-13 | CredsHolder MUST support show password on own display.<br/>For case when all USB ports are blocked |
| R-10 | S-5 | CredsHolder MUST support navigation between Account Credentials.<br/>It may be done like listing them one by one.<br/>It may be done like groups hierarchy<br/>It may be done like full text search.<br/>It may be done like priority queue with accounts where last used ones are located in the queue head. |
| R-11 | S-5 | CredsHolder MUST have enough Persistent Storage for 1000 Account Credentials. |
| R-12 | S-5 | CredsHolder MUST allow easy way to manage Accounts (add/delete/change). |
| R-13 | S-6 | CredsHolder MUST support secure boot to avoid only official firmwares. |
| R-14 | S-6 | CredsHolder MUST print title and FW version on boot to help choose new release. |
| R-15 | S-6 | CredsHolder MUST support FW upgrade. |
| R-16 | S-6 | CredsHolder MUST support FW downgrade. |
| R-17 | S-6 | CredsHolder MUST support FW rollback. |
| R-18 | S-6, S-17 | CredsHolder MUST store Accounts Credentials inside and do that without using separate application or Cloud storage. |
| R-19 | S-6 | CredsHolder MUST keep into account that "power cut" may happen at any time. |
| R-20 | S-7 | Option 1. CredsHolder SHOULD support easy installing additional components with shields. ( :-1: increased complexity, :-1: bigger case size )<br/>Option 2. Needed components SHOULD be part of MVP model. (:-1: increased prise, :+1: incremental development of usable CredsHolder version, :+1: chance to add additional functions to device, e.g. alarm clock)<br/>Option 3. CredsHolder is always DYI device. (:-1: contradiction with S-16 ) <br/>So if we decided to develop turning on a blue/green LED after pass authentication in release after MVP, then MVP hardware schema MUST contain LED which will not work in MVP version. |
| R-21 | S-8, S-12, S-14, S-17 | All source code and schematics MUST be OpenSource to allow any User assemble device and modify/build firmware. |
| R-22 | S-9 | At list application DB with Accounts Credentials MUST be on pluggable storage<br/>AND that storage MUST be independent and no one data from CredsHolder internal memory is needed to work.<br/>I don't see another way if assume that the worst case when CredsHolder is fully broken and cannot be turned on. |
| R-23 | S-10 | Application Data must be encrypted and independent on data at CredsHolder internal data |
| R-24 | S-10 | CredsHolder MUST authenticate User before grand access to application data. |
| R-25 | S-10 | If User assumes that CredsHolder cannot be stolen then it should be able to turn authentication off. So ownership of CredsHolder will mean passed authentication. |
| R-26 | S-10 | CredsHolder MUST have auto logout feature.<br/>For case when authenticated CredsHolder will be stolen. |
| R-27 | S-10 | CredsHolder SHOULD have some schema to erase/block/hide credentials from Intruder if both CredsHolder and User will be stolen. |
| R-28 | S-11 | CredsHolder case MUST be usable by any one human arm. |
| R-29 | S-14 | CredsHolder MUST have ??? |
| R-30 | S-15 | CredsHolder code/FW MUST allow to extend encryption/hash algorithm and add something else. |
| R-31 | S-16 | CredsHolder SHOULD print owner contact (:question: and name :question:).<br/>If owner lost device and someone find it, device itself will help to return it back to owner |
| R-32 | S-16 | (Alternative) CredsHolder MUST contain LoRA and GPS modules and be connected to local Meshtastic network. Owner will receive device coordinates when founder will turn device on. |
| R-33 | S-16 | CredsHolder MUST support localization to be usable in different countries. |
| R-34 | S-16 | CredsHolder License MUST allow commercial usage to allow any company make and sale CredsHolder based product. |
| R-35 | S-16 | CredsHolder SHOULD support work for humans with damaged sensor organs. |
| R-36 | S-16 | CredsHolder MAY be combined with another device, e.g. Meshtastic node. |
| R-37 | S-16 | CredsHolder MAY support import credentials from another password managers, e.g. 1Password, PassSafe, etc. |
| R-38 | S-17 | All Vendors MUST public own changes into CredsHolder sources...<br/>or data on extractable storage MUST be reusable by another CredsHolder device. |
| R-39 | S-18 | CredsHolder MUST allow to change "master password" (or it's analog). |
| R-40 | S-21 | CredsHolder MUST allow backup/restore application data/settings. |
| R-41 (optional) | S-19 (optional) | CredsHolder MUST allow password authentication. Maybe like alternative method. |
| R-42 (optional) | S-20 (optional) | CredsHolder MUST support several passwords for authentication. Or another several "master password" analogs, e.g. fingerprint, to allow notary to unblock CredsHolder.<br/>Even more better if both fingerprints/passwords - of inheritor AND notary are needed to unblock CredsHolder |
| R-43 | S-6 | CredsHolder must be separate device because it decrease amount of attack vectors |

## Entities

Everyday CredsHolder use case should looks like next: 

1. User opens login form on own PC/laptop/smartphone
1. User plugs CredsHolder
2. User authenticates on CredsHolder
3. User chooses account on CredsHolder
4. CredsHolder fills login/password in login form on User's PC/laptop/smartphone

There are next entities according to scenario above:

| Name | Comment |
| --- | --- |
| User | Citizen, Corporate, Governmental |
| Interface between Device and PC/phone/laptop | e.g. USB cable, Bluetooth, Radio channel |
| Device Controller/SOC | e.g. Arduino, NRF52, etc. Limited CPU frequency, RAM and internal flash storage volume |
| Device UI | Device hardware/? parts which allow User to authenticate on device and navigate credentials, e.g. buttons, OLED, microphone, keyboard, vibration motor, sensor display, etc. |
| Device Persistent Storage | Some flash memory to store application data, e.g. EEPROM, NAND, etc. |
| Device Case | That case MUST contain all Device UI components |
| Device FW | Bootloader, Sketch/RTOS, ... working on Device |
| Device Authentication Procedure | Password, PIN, fingerprint, voice, other biometric, mind |
| Application Storage File System | SimpleFS, JFFS, FAT, extX, UBIFS, BTRFS, XFS, etc. |
| Application Storage | (Encrypted) block device |
| Application DB | e.g. raw file, SQL, NoSQL, JSON, BSON, etc. |
| Application Data | Credentials, OTP, etc. |
| Application Settings | |
| Encryption Algorithm | e.g. AES-256 or local government algorithm |
| Hash Function | e.g. Whirlpool or SHA-512 or local government algorithm |

### Application Data. Account Credentials

Object which contains information needed to pass authentication on some service/device for User account.

Minimally it contains login and password.

But if see wider then it may contain additional fields:
* Account Name - it may be a name of web site or application, PC/server hostname or some device/application nickname
* URL of resource
* email
* phone number
* previous password
* used password generation policy
* expiration date/time

## Open Questions

* Can keyboard be connected to smartphone via NFC?

## Notes

* KEK - Key Encryption Key - key used to encrypt MEK
* MEK - Media Encryption Key - key to encrypt application data

| Encryption algorithm | e.g. AES-256 because it's well known algorithms without known backdoor and used by militaries. |
| Hash function (KDF) | e.g. Whirlpool or SHA-512. Whirlpool is less common and slower. That will increase time for KEK bruteforce. |

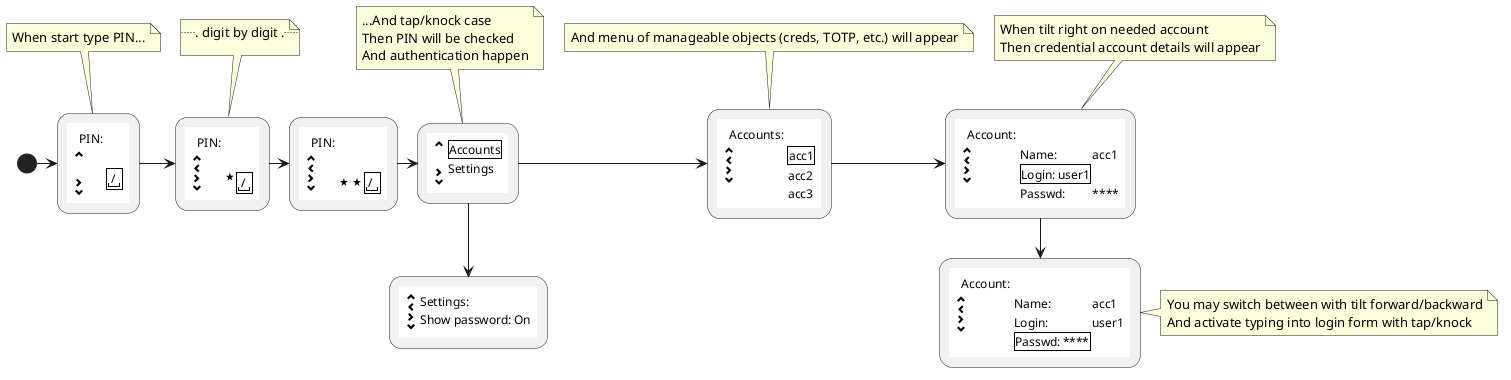
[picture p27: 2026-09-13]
proposals/creds-holder-navigation-option2.png

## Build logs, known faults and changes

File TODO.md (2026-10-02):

# TODO

| :blue_book: | Reason(s) |
| --- | :--- |
| 1 | Tracking tasks is in Markdown to avoid dependency on GitHub embedded bugtracker |
| 2 | Task list is present in each repository backup |

## Abbrevs, Terms, etc.

"Device" - CredsHolder common title in proposals, manuals and other resources

## Sub-tasks

* [x] CONTRIBUTING.md: with development environment settings, docs style, folder structure
* [x] docs(CONTRIBUTING.md): description of HLD principals
* [x] docs: collect project requirements
* [x] docs(CONTRIBUTING.md): description of LLD principals
* [x] Propose Device UI
  * [x] POC1. Tilt detection on Arduino
  * [x] POC2. Tilt detection on NRF52840
* [x] Propose Device HW storage
* [x] Propose Device (encrypted) data storage
* [x] Propose Device file system
* [x] Propose menu navigation
  * without auth
  * menu Accounts
  * typing login/password
  * no encryption, no storage on microSD, hard-coded accounts
* [x] vibration feedback on tilt up to enough angle
* [ ] build test objects/exec in separate folder
* [x] build .o files for tests using all .cpp files, not .t.cpp only
* [ ] scope code within new C++ namespace "creds_holder"
* [x] auto generation compiler_commands.json
* [ ] Implement "insulation" as template class
* [ ] Include "creds_holder.hpp" globally via CFLAGS/CPPFLAGS/CXXFLAGS instead of explicit one in each source file
* [ ] Build Adafruit_nRFCrypto under AUnit
* [ ] Check U8x8 log class - maybe it's better in memory debug oled then OledInMem
* [ ] Exclude .t.cpp files from build for target platform and avoid "if defined(EPOXY_DUINO)" guards usage
* [ ] propose authentication
  * (blocked) vibration motor module is in delivery
* [ ] Implement calibration
* [ ] Implement tutorial
* [ ] Implement authentication by hard-coded pin
* [ ] Implement read file from microSD card with partition "storage" formatted with FAT16
* [ ] Implement formatting partition "storage" as VeraCrypt volume
* [ ] Implement reading from VeraCrypt volume
  * [ ] migrate from Crypto to nRFCrypto (add abstraction?)
* [ ] Implement PIN on LUKS header in internal storage
* [ ] Implement set PIN by User
* [ ] Implement new way for accept/enter action - via tap/knock
  * (blocked) piezo electronic sensor is in delivery
* [ ] propose object storage
  * [~] find OpenSource applications which code may be reused
* [~] propose secure burn/boot
* [-] propose interface between Device and user device (PC/smartphone)
* [ ] propose device case
* [ ] propose OS (sketch only or RTOS or ...)
* [ ] propose plugins schema in SW
* [ ] propose schematic
* [ ] implement tilt detection in non vertical position, e.g. lying on the sofa
* [ ] implement tilt detection during moving in vehicle 
* [ ] ROADMAP.md: propose MVP and Roadmap
* [ ] CONTRIBUTING.md: development process principals
* [~] TODO.md: plan development
* [ ] TODO.md: estimate development

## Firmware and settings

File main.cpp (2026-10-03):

// CredsHolder (Hardware Credential Manager)
// Copyright (C)  2026  Ivan Efimov aka MuteSpirit <mutespirit@yandex.ru>.
//
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
// You should have received a copy of the GNU General Public License
// along with this program.  If not, see <https://www.gnu.org/licenses/>.
#include "src/creds_holder.hpp"
#include <Arduino.h>

#include "Embedded_Template_Library.h"
#include "etl/array.h"

// #include "src/auth.hpp"
#include "src/cli.hpp"
#include "src/model/account.hpp"
#include "src/model/iterator.hpp"
#include "src/model/storage.hpp"
#include "src/ssd1306_oled.hpp"
#include "src/version.hpp"
#include "src/display_ui.hpp"
#include "src/device.hpp"
#include "src/accounts_menu.hpp"
#include "src/account_menu.hpp"
#include "src/settings_menu.hpp"
#include "src/settings.hpp"
// #include "src/auth_form.hpp"
#include "src/memory_block_storage.hpp"
#include "src/snake_game.hpp"

#if defined(ARDUINO_ARCH_NRF52)

#include "src/nrf52840/keyboard.hpp"
TinyUsbKeyboard keyboard;

#else

#include "src/arduino/keyboard.hpp"
ArduinoKeyboard keyboard;

#endif

// Baud rate for serial port
#define SERIAL_BAUD_RATE 115200

#define SHOW_SPLASHSCREEN 1000 // ms

Settings settings;

SSD1306I2C oled;

CredsHolderOutputs deviceOutputs;

CredsHolderInputs userInputs(deviceOutputs);

// PasswordWandAuth authenticator;

// TODO: move to callback
// assertTrue(ebs.init(encStoreKey, encStoreKeyLen));

MemoryBlockStorage<4098, 32> mbs;
ModelStorage<Account> modelStore(mbs);

// Create on demand ???
// AuthForm authForm(oled, userInputs, authenticator);
AccountsMenu accountsMenu(oled, userInputs, modelStore);
AccountMenu accMenu(oled, userInputs, keyboard);
SettingsMenu settingsMenu(oled, userInputs, settings);

SnakeGame tutorial(oled, userInputs);

DisplayUI ui(oled, userInputs/*, authForm*/, accountsMenu, accMenu, settingsMenu);

///////////////////////////////////////////////////////////////////////////////////////////////////////////////
void
setup()
{
    if (deviceOutputs.setup()) {
        if (Serial) { Serial.println(F("DeviceOutputs::setup failed")); }
    }

    // <debug>
    etl::array<Account, 3> aa {{
        {"name0", "user0", "passwd0"},
        {"name1", "user1", "passwd1"},
        {"NAME2", "USER2", "PASSWD2"}
    }};
    for (auto& acc : aa) {
        modelStore.add(acc);
    }
    // </debug>

    // Init keyboard before Serial to avoid troubles
    keyboard.setup();

    Serial.begin(SERIAL_BAUD_RATE);

    // Waiting Serial initialization forever means stuck forever if Arduino IDE
    // Serial Monitor (or analog app) does not run
    // while (!Serial) { delay(50); };
    delay(50);

    // debug: hard-coded Accounts has been added
    // TODO: use pattern Observer
    accountsMenu.notifyModelStoreUpdated();

    if (Serial) {
        print_welcome(Serial);
    }

    oled.setup();
    oled.setFont(u8x8_font_8x13_1x2_f);

    oled.clear();
    oled.home();
    print_welcome(oled);
    oled.display();
    delay(SHOW_SPLASHSCREEN);

    // if (Serial) {
    //     for (ModelIterator<Account> it = modelStore.cbegin(); it != modelStore.cend(); ++it) {
    //         Serial.println((*it).name);
    //     }
    // }
    if (!userInputs.setup()) {
        if (Serial) { Serial.println(F("MPU6050 Error")); }
    }

    // cli_init(settings.cli_turn_on_);

    // If you'd like to play "Snake Game" uncomment next ...
    // tutorial.setup();
    // tutorial.activate();
    // tutorial.draw();
    // ... and comment next line
    ui.setup();
}

void
loop()
{
    static bool startup_delay_done = false;
    if (!startup_delay_done) {
        delay(750);
        startup_delay_done = true;
        //
        // oled.clear();
        // oled.home();
        // oled.println("DEBUG");

    }
    // TODO: auto register "loop_step" handlers ???

    // <debug>
    // if (Serial) Serial.println(F("."));
    // delay(1000);

    // cli_loop_step();

    userInputs.loop_step();

    // If you'd like to play "Snake Game" uncomment next ...
    // tutorial.loop_step();
}

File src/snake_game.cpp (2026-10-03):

// CredsHolder (Hardware Credential Manager)
// Copyright (C)  2026  Ivan Efimov aka MuteSpirit <mutespirit@yandex.ru>.
//
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

// Snake game code is base on project: https://github.com/aydakikio/arduino_snake
//
// MIT License
//
// Copyright (c) 2025 aydakikio
//
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
// THE SOFTWARE IS PROVIDED "AS IS", WITHOUT WARRANTY OF ANY KIND, EXPRESS OR
// IMPLIED, INCLUDING BUT NOT LIMITED TO THE WARRANTIES OF MERCHANTABILITY,
// FITNESS FOR A PARTICULAR PURPOSE AND NONINFRINGEMENT. IN NO EVENT SHALL THE
// AUTHORS OR COPYRIGHT HOLDERS BE LIABLE FOR ANY CLAIM, DAMAGES OR OTHER
// LIABILITY, WHETHER IN AN ACTION OF CONTRACT, TORT OR OTHERWISE, ARISING FROM,
// OUT OF OR IN CONNECTION WITH THE SOFTWARE OR THE USE OR OTHER DEALINGS IN THE
// SOFTWARE.
#include "snake_game.hpp"

#include "creds_holder.hpp"

#include <new>
#include <Arduino.h>

#ifdef U8X8_HAVE_HW_I2C
#include <Wire.h>
#endif

#include <U8g2lib.h>

#include "oled.hpp"
#include "device_inputs.hpp"


////////////////////////////////////////////////////////////////////////////////
#define GRID_SIZE 6
#define SCREEN_WIDTH 126
#define SCREEN_HEIGHT 54

// Max snake length
#define SNAKE_MAX 150

#define DRAW_INTERVAL 42

////////////////////////////////////////////////////////////////////////////////
// Store constant strings in PROGMEM (flash memory) to save RAM
const char str_score[] PROGMEM = "Score:";
const char str_best[] PROGMEM = "Best:";
const char str_you_win[] PROGMEM = "YOU WIN!";
const char str_max_length[] PROGMEM = "Max length!";
const char str_game_over[] PROGMEM = "GAME OVER";
const char str_new_high[] PROGMEM = "NEW HIGH SCORE!";
const char str_press_btn[] PROGMEM = "Make any tilt...";

////////////////////////////////////////////////////////////////////////////////
class SnakeGameImpl
{
public:
    struct Point {
        int8_t x, y;
    };

public:
    SnakeGameImpl(Oled&, DeviceInputs&);

    void init(BlindCall nextMenuCb, BlindCall prevMenuCb);

    void activate();
    void deactivate();

    bool setup();
    void loop_step();

    void drawGame();
    void drawGameOver();

    void generateFood();
    void resetHighScore();

    void moveSnake();
    void checkCollisions();
    void growSnake();
    void resetGame();

    void up();
    void down();
    void left();
    void right();
    void reset();

public:
    U8G2_SSD1306_128X64_NONAME_F_HW_I2C u8g2;

    Oled& oled_;
    DeviceInputs& userInputs_;
    BlindCall nextMenuCb_;
    BlindCall prevMenuCb_;
    bool activated {false};

    Point snake[SNAKE_MAX];
    int snake_length {3};
    Point food;

    bool input_detected {false};

    int8_t current_direction {0};
    int8_t next_direction {0};
    bool is_direction_changed {false};

    int score {0};
    int high_score {0};
    bool game_over {false};
    bool food_eaten {false};
    bool new_high_score {false};

    unsigned long last_move {0};
    unsigned long last_input {0};
    unsigned long last_draw {0};
    unsigned long game_speed {500};
    unsigned long min_speed {100};

    // Buffer for reading strings from PROGMEM
    char buffer[20];

    // Track if we need to redraw
    bool needs_redraw {true};
};

// TODO: restore keeping results in EEPROM in future versions
// #include <EEPROM.h>
// // EEPROM addresses
// #define EEPROM_HIGH_SCORE_ADDR 0
// #define EEPROM_MAGIC_ADDR 2
// #define EEPROM_MAGIC_VALUE 42

////////////////////////////////////////////////////////////////////////////////
SnakeGameImpl::SnakeGameImpl(Oled& oled, DeviceInputs& userInputs)
    : u8g2(U8G2_R0, /* reset=*/ U8X8_PIN_NONE)
    , oled_(oled)
    , userInputs_(userInputs)
{
    memset(snake, 0, sizeof(snake));
    memset(buffer, 0, sizeof(buffer));
}

void
SnakeGameImpl::init(BlindCall nextMenuCb, BlindCall prevMenuCb)
{
    nextMenuCb_ = nextMenuCb;
    prevMenuCb_ = prevMenuCb;
}

void
SnakeGameImpl::activate()
{
    userInputs_.set(DeviceInputs::UserAction::left, BlindCall::make(this, &SnakeGameImpl::left));
    userInputs_.set(DeviceInputs::UserAction::right, BlindCall::make(this, &SnakeGameImpl::right));
    userInputs_.set(DeviceInputs::UserAction::up, BlindCall::make(this, &SnakeGameImpl::up));
    userInputs_.set(DeviceInputs::UserAction::down, BlindCall::make(this, &SnakeGameImpl::down));
    userInputs_.set(DeviceInputs::UserAction::enter, BlindCall::make(this, &SnakeGameImpl::reset));

    activated = true;
}

void
SnakeGameImpl::deactivate()
{
    activated = false;

    userInputs_.unset(DeviceInputs::UserAction::left);
    userInputs_.unset(DeviceInputs::UserAction::right);
    userInputs_.unset(DeviceInputs::UserAction::up);
    userInputs_.unset(DeviceInputs::UserAction::down);
    userInputs_.unset(DeviceInputs::UserAction::enter);
}

bool
SnakeGameImpl::setup() {
    u8g2.begin();

    // TODO: restore keeping results in EEPROM in future versions
    // loadHighScore();

    snake[0].x = GRID_SIZE * 10;
    snake[0].y = 8 + GRID_SIZE * 4;

    snake[1].x = GRID_SIZE * 9;
    snake[1].y = 8 + GRID_SIZE * 4;

    snake[2].x = GRID_SIZE * 8;
    snake[2].y = 8 + GRID_SIZE * 4;

    generateFood();

    // TODO: use TNRG
    randomSeed(analogRead(A2));

    return true;
}

void
SnakeGameImpl::up()
{
    if (game_over) {
        resetGame();
        needs_redraw = true;
        delay(500);
    }

    if (current_direction != 3) {
        next_direction = 2;
        is_direction_changed = true;
        input_detected = true;
        last_input = millis();
    }
}

void
SnakeGameImpl::down()
{
    if (game_over) {
        resetGame();
        needs_redraw = true;
        delay(500);
    }

    if (current_direction != 2) {
        next_direction = 3;
        is_direction_changed = true;
        input_detected = true;
        last_input = millis();
    }
}

void
SnakeGameImpl::left()
{
    if (game_over) {
        resetGame();
        needs_redraw = true;
        delay(500);
    }

    if (current_direction != 0) {
        next_direction = 1;
        is_direction_changed = true;
        input_detected = true;
        last_input = millis();
    }
}

void
SnakeGameImpl::right()
{
    if (game_over) {
        resetGame();
        needs_redraw = true;
        delay(500);
    }

    if (current_direction != 1) {
        next_direction = 0;
        is_direction_changed = true;
        input_detected = true;
        last_input = millis();
    }
}

void
SnakeGameImpl::reset()
{
    resetHighScore();
    needs_redraw = true;
    delay(500);
}
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

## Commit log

2026-08-11 docs(README.md): update news and name in presentation slide
    Remove news related to PusswordWand.
    Add more reasons to start separate project.
    Changed device title on slide from PasswordWand to CredsHolder.
2026-08-11 plan(TODO): planing proposals stage
    .gitignore: get *.html out of git track
    because they are autogenerated
    Makefile: target "html" to render GitHub Markdown into HTML
    because we need to see the result before push
    TODO.md: tasks for proposing, 1st example of Reasons in doc
2026-08-12 docs: propose authentication
    proposals/creds-holder.md: add another HW creds manager projects
    proposals/creds-holder-auth.md: started proposals for authentication,
    approximately chose device UI (encoder and buttons) + password for MVP
2026-08-15 docs(ui): start HLD about CredsHolder UI
    Add requirement and part of contradictions.
    Three perspective ways: touch LCD, position sensor and encoder+buttons
    My favorite is "position sensor for movements of device", sounds cool
    and unique
2026-08-16 docs(creds-holder-hardware): add draft notes about planned hardware
    Several notes about MCU: Arduino, nrf52840 and stm32,
    and about position sensors
2026-08-17 docs(ui): suggest 3 variants for device UI
    1. Output is 0.96inch OLED and vibration motor. Input is device movements detected by position sensor (accelerometer + gyroscope)
    2. Touch LCD is as both input and output
    3. Output is 0.96inch OLED and encoder + group of buttons as input
    Need to make POC to prove possibility of 1st one
2026-08-23 feat(poc): POC for UI with MPU6050 and 0.96 inch OLED
    Device tilts (on left, on right, forward, backward) can be enough stably
    detected.
    Note: tilt is detected in software when device position returned back to
    normal position.
    Work is stable during about 50 min.
    TODO: knock detection
2026-08-23 fix(poc): fixed decrease FIFO rate to 40 Hz
    i2cdev library code is not so clear, usage of SMPLRT_DIV are located
    in two different places and even happen two times.
    Currently used
    and
    is also enough stable.
    But anyway on any speed there will be FIFO overflow eventually.
2026-08-23 feat(poc-2): POC No2. UI with MPU6050 and 0.96 inch OLED on NRF52840 Pro Micro
    Tap/knock detection using position sensor MPU6050 was failed due to
    noises from taking device in arms.
    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
    [ui-mpu-6050-with-oled-on-nrf52840.fzz]
2026-08-23 feat(fritzing): make new Fritzing component NRF52840 Pro Micro
    That component has been done because exist fritzing part for it has not
    been founded.
    Also added fritzing parts for components needed for next POCs:
    * OLED 128x64 I2C
    * microSD card reader
    * vibration motor module
    * Piezo sensor
2026-09-11 docs(creds-holder-hardware): add ads and cons for different link types between CredsHolder and PC/phone
    Bluetooth looks modern and more usable. But USB cable is more simple,
    well known and usable in more corner cases.
2026-09-17 feat: PasswordWand MVP draft adaption to NRF52840
    !!! Warning !!!
    * Only compilation pass.
    * There were no test on the board.
    * BSP layer has a trouble with "Serial" global object definition.
    That must be fixed in first turn
    Planned MVP:
    * auth form + accounts menu + settings menu
    * not encrypted storage in internal NVM flash
    Adaptions:
    * UI has been changed from Rotary Encoder + buttons to MPU6050 position
    sensor
    * Keyboard class reimplemented using TinyUSB
    * SSD1306 display has been supported using U8g2lib
    [ui-mpu-6050-with-oled-on-nrf52840.fzz]
2026-09-17 fix(oled): fix error with ambiguous Print as a base class for Oled
    Reason was in diamond inheritance:
    Oled -> Print
    SSD1306I2C -> U8G2 -> Print
    SSD1306I2C stop inherit U8G2 and start aggregate it instead.
    Reason: we don't want to change U8g2 library sources.
    [main.cpp]
2026-09-17 fix(internal storage): avoid redefinition "Serial" global object
    Reason:
    Include <EEPROM.h> then include <Arduino.h> or <Adafruit_TinyUSB.h>
    Defense by explicit define USE_TINYUSB before "#include <EEPROM.h>"
2026-09-28 doc(CONTRIBUTING): add note about configure Board Manager for Pro Micro nRF52840
    Add Arduino IDE configuration steps according to article mentioned in
    CONTRIBUTING.md
2026-09-28 fix(test): adapt user inputs imitation class too
    ImitatedUserInputs inherited UserInputs instead of DeviceInputs as
    needed now. Fixed.
    All code from "src/memory_block_storage.cpp" has been moved into
    "src/memory_block_storage.hpp" because it's template class.
    But tests included cpp and fail on compilation.
    Fixed by including header instead.
2026-09-28 docs(CONTRIBUTING): fix manual about Arduino IDE preparation and add similar section about arduino-cli
    https://github.com/pdcook/nRFMicro-Arduino-Core
    has been forked into
    https://github.com/MuteSpirit/nRFMicro-Arduino-Core
    to be able add needed fixes and upgrade used libraries
    Developer env config manual has been updated accordingly
2026-09-28 docs(CONTRIBUTING): add section about unit tests
    * reasons to use
    * file naming
    * ifdef guards to exclude from board target build
    * ...TestHelper class usage
2026-09-28 fix(Makefile): unit tests compilation with ETL
    * Add more comments about unit test build
    * Add ETL into ARDUINO_LIBS to force includes work for ETL too
    * Define next macro explicitly to avoid conflicts between STL and ETL
    definitions and usage
    * ETL_NO_STL
    * ETL_NO_INITIALIZER_LIST
    That has been done both for target and unit test builds
2026-09-28 feat: mock classes for unit tests is located in src/t now. Add ImitatedKeyboard and OledInMem.
    To explicitly see classes needed for unit tests only they have been
    moved into "src/t/" folder.
    Add classes:
    * ImitatedKeyboard - just Keyboard stub implementation which do nothing
    * OledInMem - Oled interface implementation which copy printed strings
    into internal string buffer. Only text mode.
2026-09-28 fix: use ETL from installed Arduino IDE libraries instead of git submodule
    Preprocessor could not find ETL headers to include because of absence
    next include:
    #include "Embedded_Template_Library.h"
    Fix:
    * Include like above has been added
    * "lib/etl" git submodule has been removed
2026-09-30 feat: For unit tests -std=gnu11 -> -std=gnu17, -std=gnu++11 -> -std=gnu++14
    Set the same C/C++ standards to use in compilation as in updated
    nRFMicro-like-Boards BSP package.
2026-10-02 feat: AccountsMenu and AccountMenu works together
    Navigation between menus - works.
    Navigation between accounts - works.
    Navigation between account fields - works.
    Typing login/password as keyboard - works.
    Issues:
    * Accounts list is empty just after sketch start.
    It's needed to tilt "up" couple of times to draw it.
    [main.cpp]
2026-10-02 fix(AccountsMenu): correct show accounts after device turn on
    Issue: on device turn on AccountsMenu draw happens incorrect: there is
    title on screen but no one account
    Reason: hard-coded accounts have been added after AccountsMenu creation.
    Fix: explicit method to update UISelectionList inside AccountsMenu after
    Model Storage add(...) calls.
    TODO: Oled::getRows() return wrong value for real screen
    [device.cpp]
2026-10-02 feat: small demo variant proving UI proposals
    * Demo variant:
    * no authentication
    * no storage on flash
    * 3 hard-coded accounts
    * accounts menu
    * account fields menu
    * typing login and password
    * navigation with device tilts (forward, backward, clockwise and counterclockwise)
    * vibration motor to feedback User about correct tilt angle
    [poc-vibro-motor-nrf52840.fzz]
2026-10-02 feat: compiler_commands.json generation
    Add compilation database generation using "compiledb".
    Install it preliminary.
    python3 -m pip install --user compiledb
    Also added as commented command compilation database creation with
    arduino-cli option "--only-compilation-database". Switch to it if more
    preferable.
    Add makefile target "help" to print human readable usage for makefile
    targets.
    Fix DEPS makefile variable assignment: "find" command had syntax error.
2026-10-03 feat: Adapted Snake Game
    Adapted project https://github.com/aydakikio/arduino_snake
    License: MIT
    "Snake Game" will be used as tutorial for non standard CredsHolder
    navigation system based on tilts.
    main.cpp contains comments about (un)comment needed lines to run Sname
    Game by default.
    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
2026-10-11 feat: add KnockSensor to detect single and double knocking
    * POC No 5 with piezoelectric sensor connection to pin A0
    * KnockSensor class to detect single and double knocks
    * Add hint screen in tutorial "Snake Game"
    * Add double knock as UserAction::enter action
    * Integrate SnakeGame into DisplayUI. It'll appear after device start.
    * Set UI navigation:
    Snake Game <-> Accounts Menu <-> AccountMenu
    * Small fixes into Makefile to more accurately build HTML files and run
    clean in poc/ subfolder.
2026-10-12 feat(SQLite3): add SQLite3 v3.42.2 amalgamation
    SQLite3 amalgamation sources has been taken from project
    https://github.com/siara-cc/esp32_arduino_sqlite3_lib
    That files has been used because that lib has similar SQLite3 VFS
    implementation as planned and SQLite3 defines/options has been optimized
    for similar embedded system - ESP32.
2026-10-15 feat(SQLite3 VFS): Ability to create SQLite3 DB on block device over FatFS
    * Draft implementation of SQLite3 VFS which use TinyFATFS library to
    access block device
    * Implemented methods:
    * xOpen
    * xDelete
    * xFullPathname
    * xClose
    * xRead
    * xWrite
    * xTruncate
    * xSync
    * xFileSize
    * xSectorSize
    * Disk image file created by unit test contains format errors but anyway
    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
2026-10-17 fix(build): fix build in Arduino IDE
    After regeneration SQLite3 amalgamation the explicit include for
    "config_ext.h" has been removed.
    SQLite3 sources provides SQLITE_CUSTOM_INCLUDE macro to allow user
    inject own header include inside sqlite3.c file.
    And SQLITE_CUSTOM_INCLUDE definition for unit test build or arduino-cli one in Makefile is not an issue.
    But do the same for Arduino IDE build is not so trivial and it requires change build settings in BSP package.
    So local manual patch has been used for sqlite3.c:
    Include SQLITE_CUSTOM_INCLUDE or include "config_ext.h"
    So SQLITE_CUSTOM_INCLUDE definitions in Makefile have been removed.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
